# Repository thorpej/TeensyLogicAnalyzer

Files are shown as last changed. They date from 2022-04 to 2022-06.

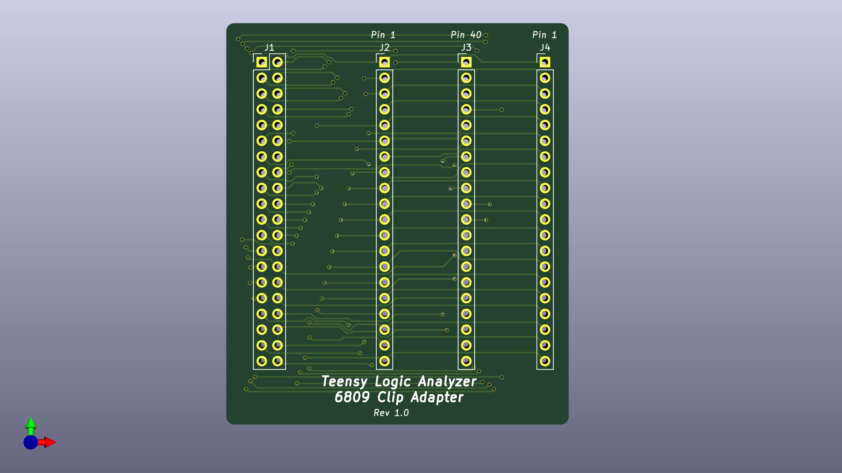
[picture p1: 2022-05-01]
clip-adapter-6809/clip-adapter-6809-pcb.jpg

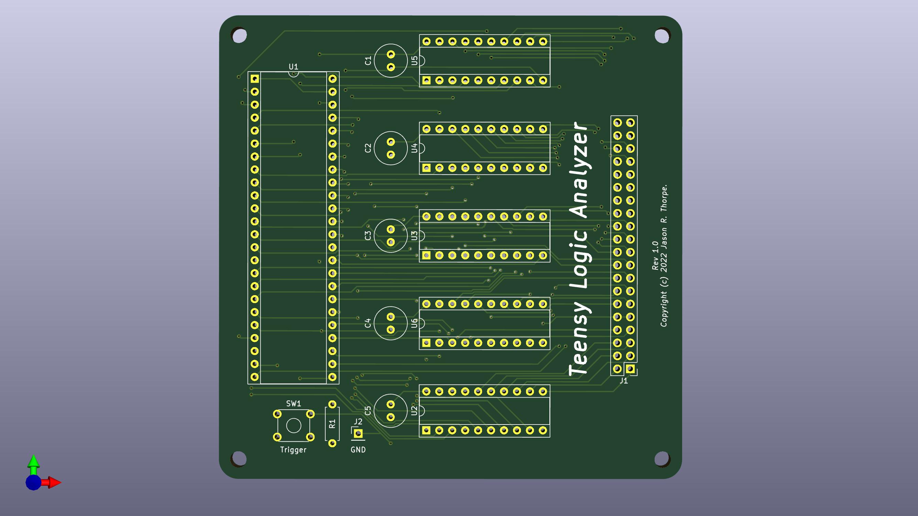
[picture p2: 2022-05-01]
analyzer-board/analyzer-board-pcb.jpg

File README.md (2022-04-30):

# TeensyLogicAnalyzer
Simple logic analyzer for 8-bit CPUs based on Jeff Tranter's 8-bit CPU logic analyzer

This is a work-in-progress.  You can find Jeff's work [here](https://github.com/jefftranter/6502).

This version aims to support a wide variety of 8-bit CPUs (so long as they fit in a 40-pin DIP)
and be easily expandable to new CPU types (e.g. 8080 and 8088) through the use of off-board adapter
modules, as well as to support sampling the full complement of control signals on the supported CPUs.

The main board is very similar to Jeff's original: it contains the Teensy 4.1, input buffers to
level-shift the 5V TTL signals from the target CPU down to the 3.3V levels supported by the Teensy,
a manual trigger button, and a ground reference pin (as a convenience).

The main difference is the use of a single keyed 40-pin IDC header.  This header's pinout does not
correspond directly to any single CPU type, but merely provides the input to the analyzer.
Individual adapter modules mate the analyzer to a specific CPU.  These adapter modules also contain
a 40-pin keyed IDC header, as well as 2 (optionally 3) rows of 1x20 pin headers for connecting a 40-pin
DIP clip to the adapter.  The adapter maps the target CPU's pin configuration to the analyzer's input
pins.  In addition to providing future expandability, it also keeps the manufacturing cost of the boards
low (some PCB fabricators charge as little as $5 + shipping for a run of 10 if the board is smaller
than 100mm x 100mm).  The analyzer board is approximately 91mm x 91mm (roughly 3.5 inches square), and
uses all through-hole components to make it easy to build.

In addition, I plan to make some specific enhancements to the 6809 support, including:
- Support additional signals on the 6809 (e.g. BS, BA, /FIRQ, /HALT).
- Properly notice instruction fetch on 6809E (by watching the LIC signal).
- Improve 6809 dissasembly (decode all of the addressing modes, as well as the 2-byte opcodes).

Beause the 6809E enhancements I want to make require additional signals to be routed, I needed
to make a new board anyway, which is why this project exists.

More to come.  Stay tuned!

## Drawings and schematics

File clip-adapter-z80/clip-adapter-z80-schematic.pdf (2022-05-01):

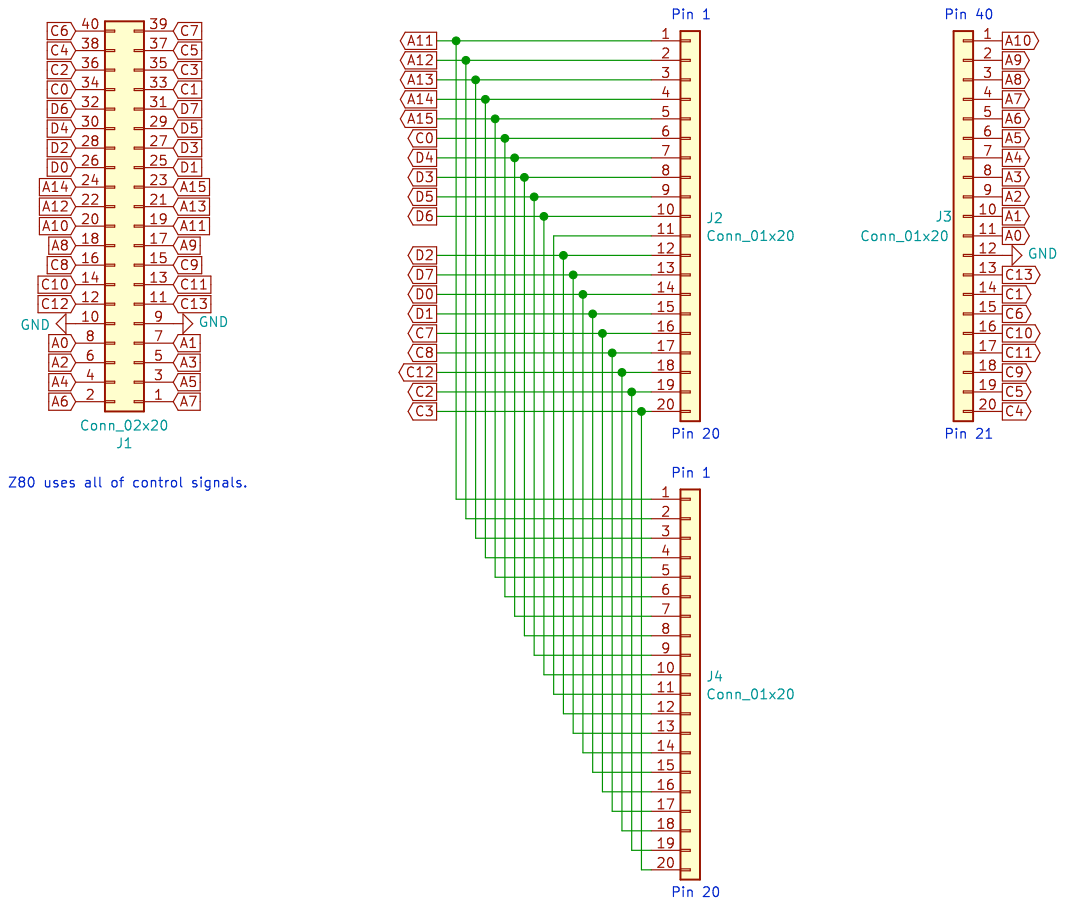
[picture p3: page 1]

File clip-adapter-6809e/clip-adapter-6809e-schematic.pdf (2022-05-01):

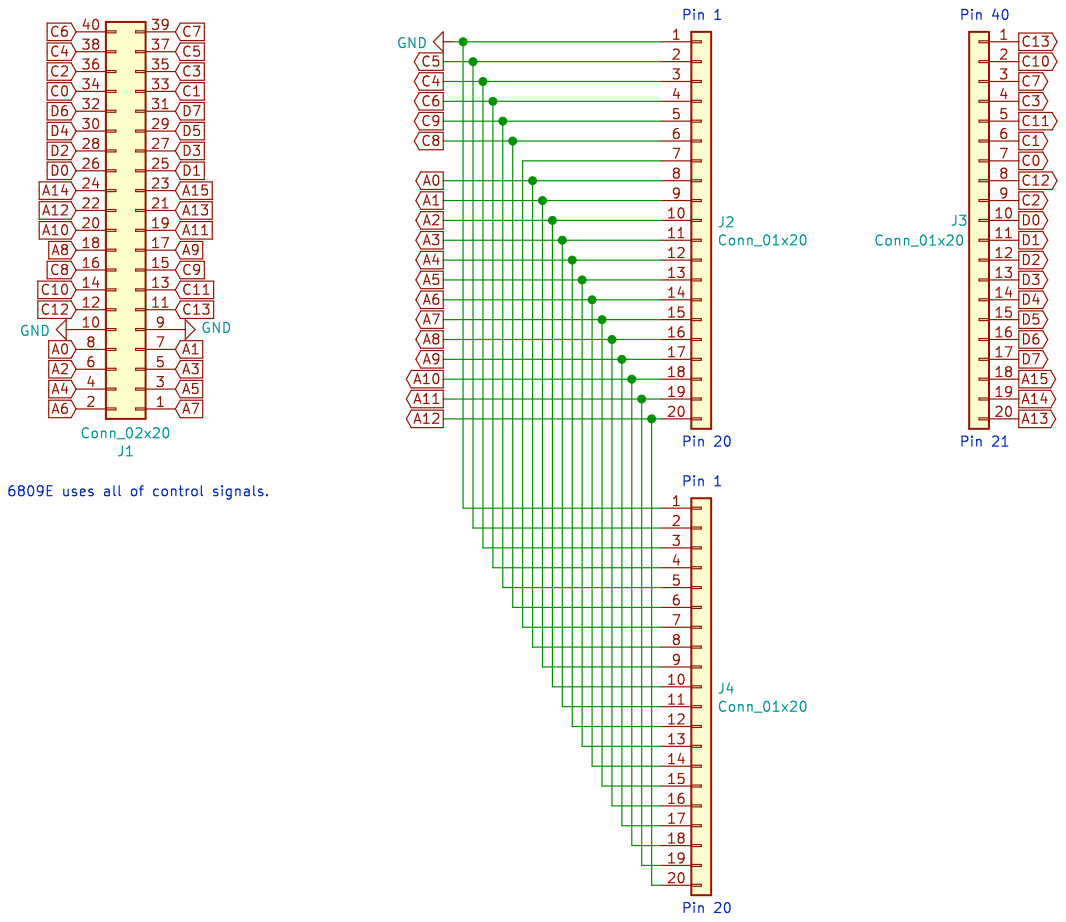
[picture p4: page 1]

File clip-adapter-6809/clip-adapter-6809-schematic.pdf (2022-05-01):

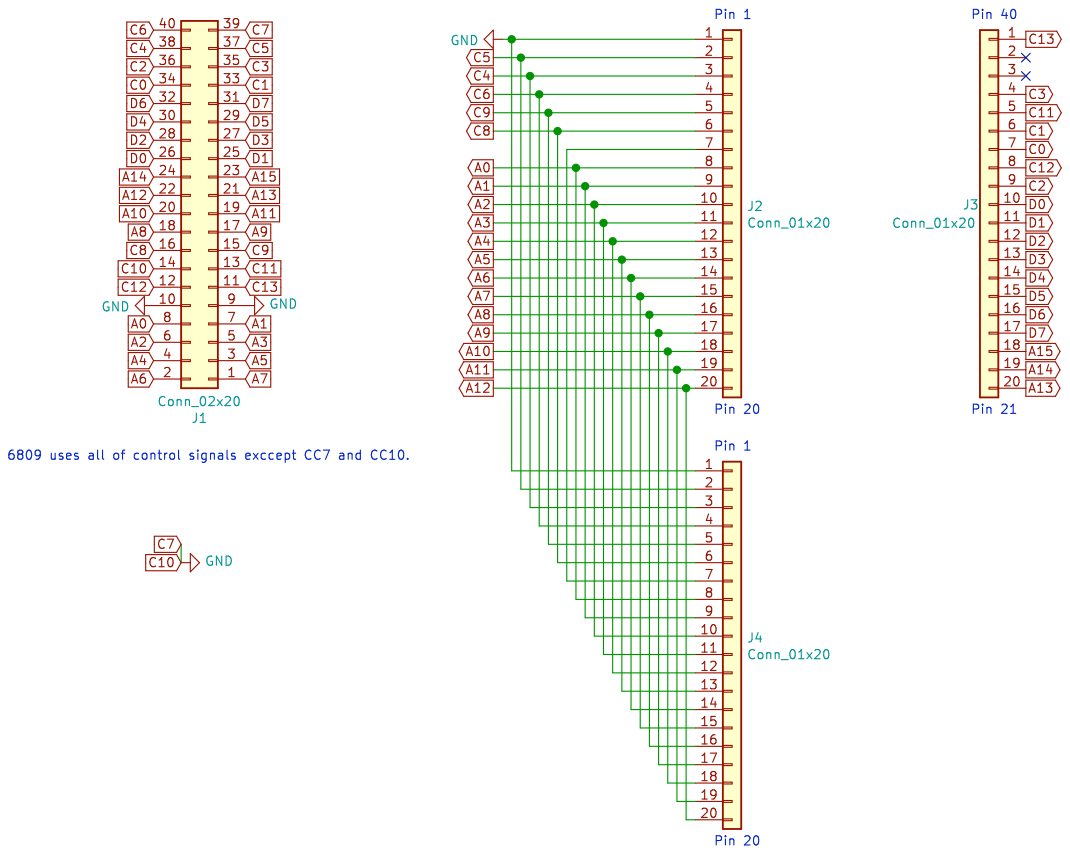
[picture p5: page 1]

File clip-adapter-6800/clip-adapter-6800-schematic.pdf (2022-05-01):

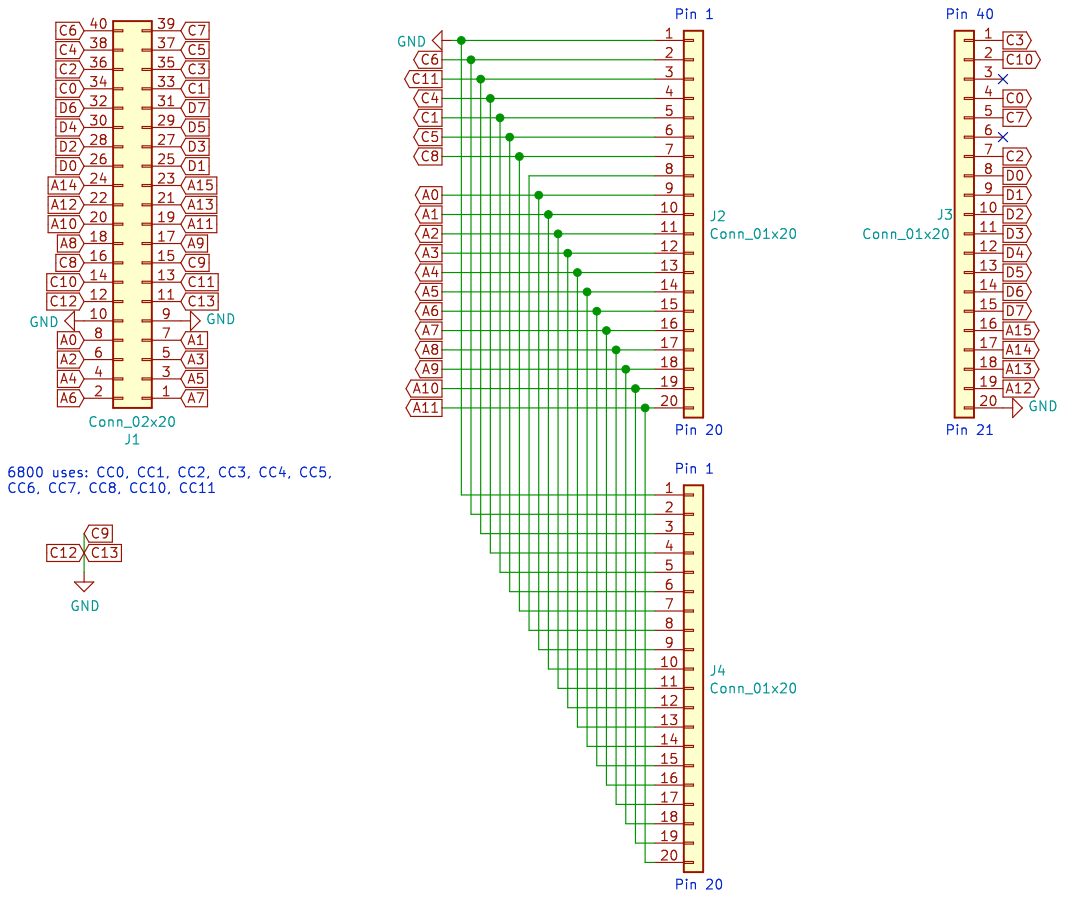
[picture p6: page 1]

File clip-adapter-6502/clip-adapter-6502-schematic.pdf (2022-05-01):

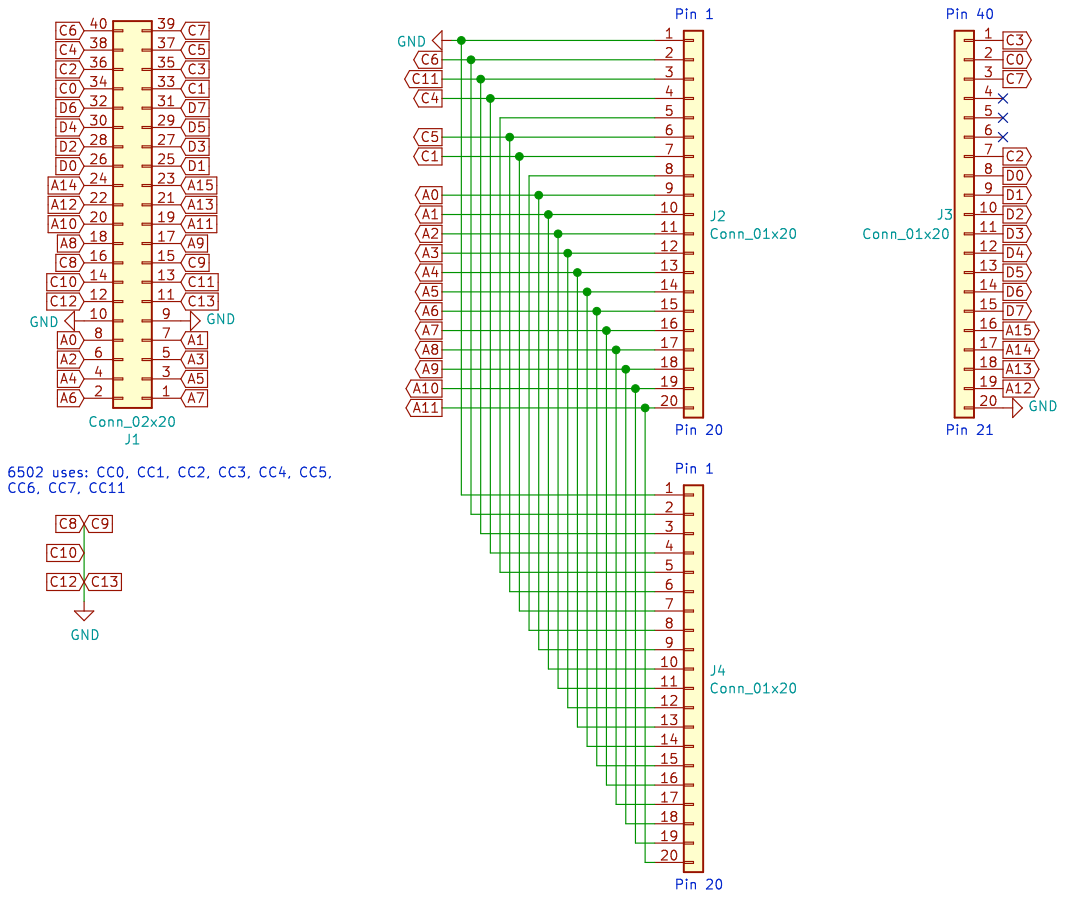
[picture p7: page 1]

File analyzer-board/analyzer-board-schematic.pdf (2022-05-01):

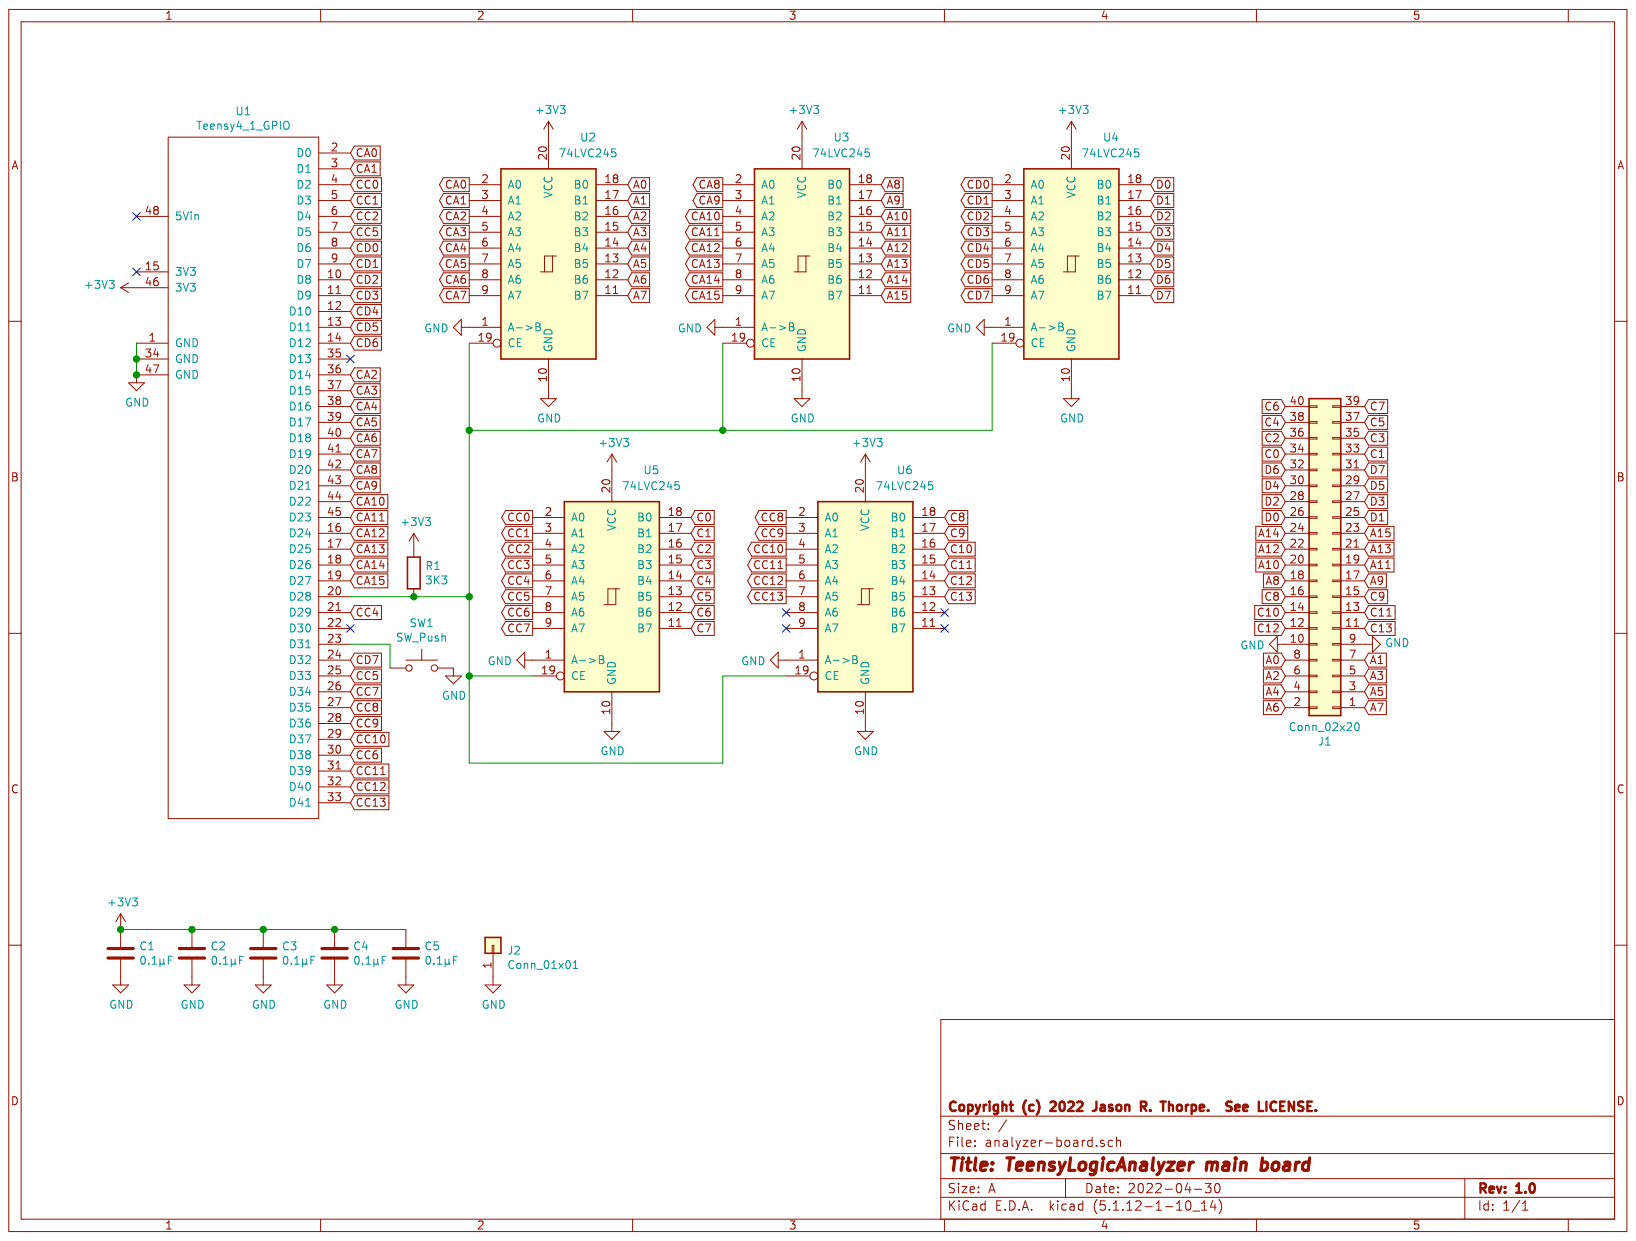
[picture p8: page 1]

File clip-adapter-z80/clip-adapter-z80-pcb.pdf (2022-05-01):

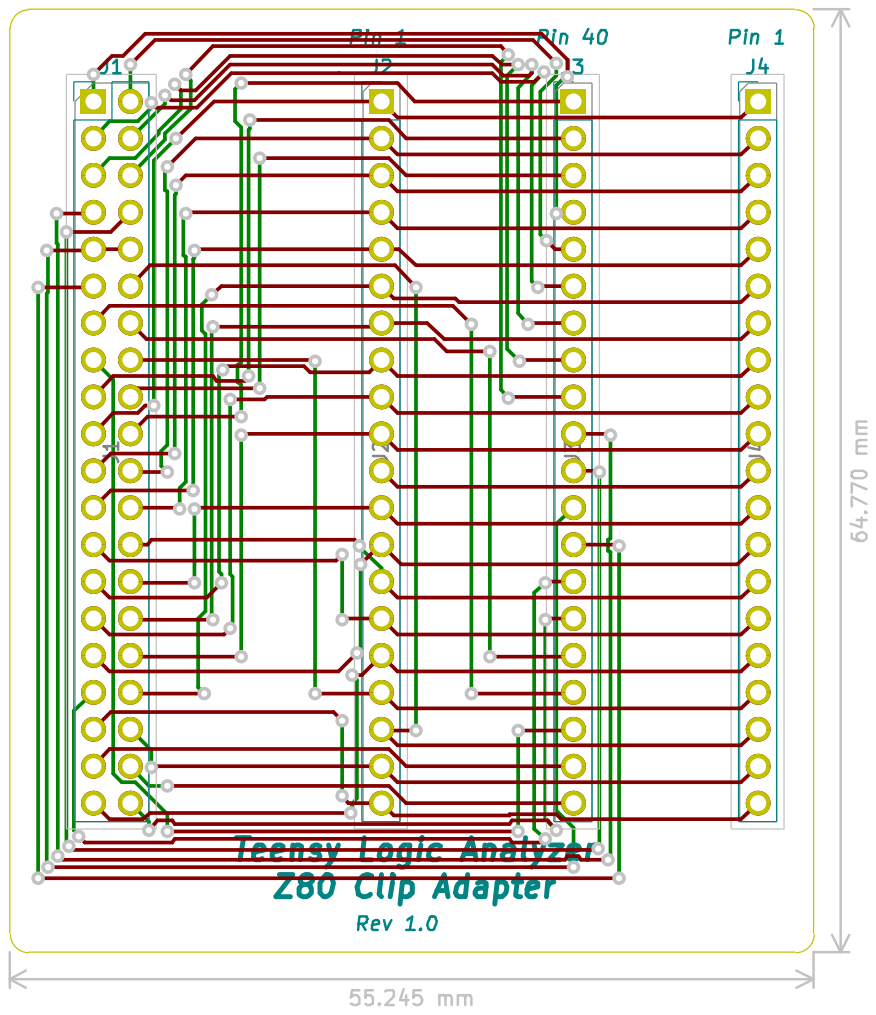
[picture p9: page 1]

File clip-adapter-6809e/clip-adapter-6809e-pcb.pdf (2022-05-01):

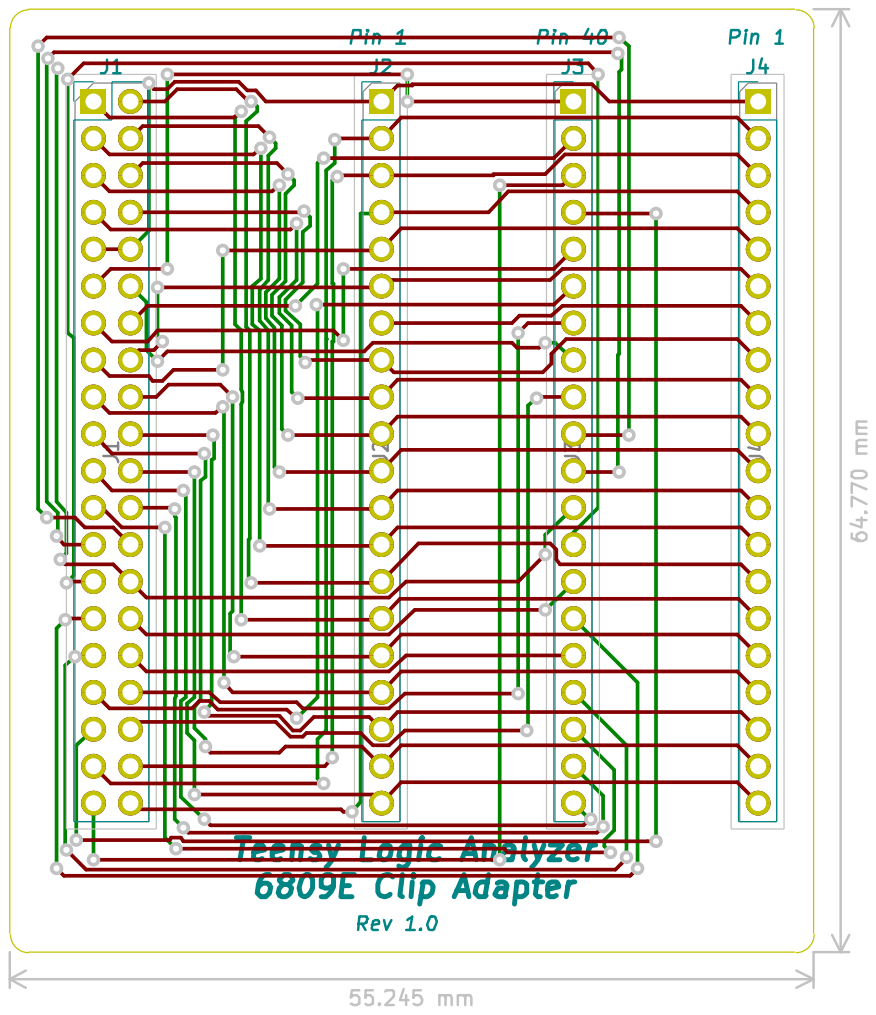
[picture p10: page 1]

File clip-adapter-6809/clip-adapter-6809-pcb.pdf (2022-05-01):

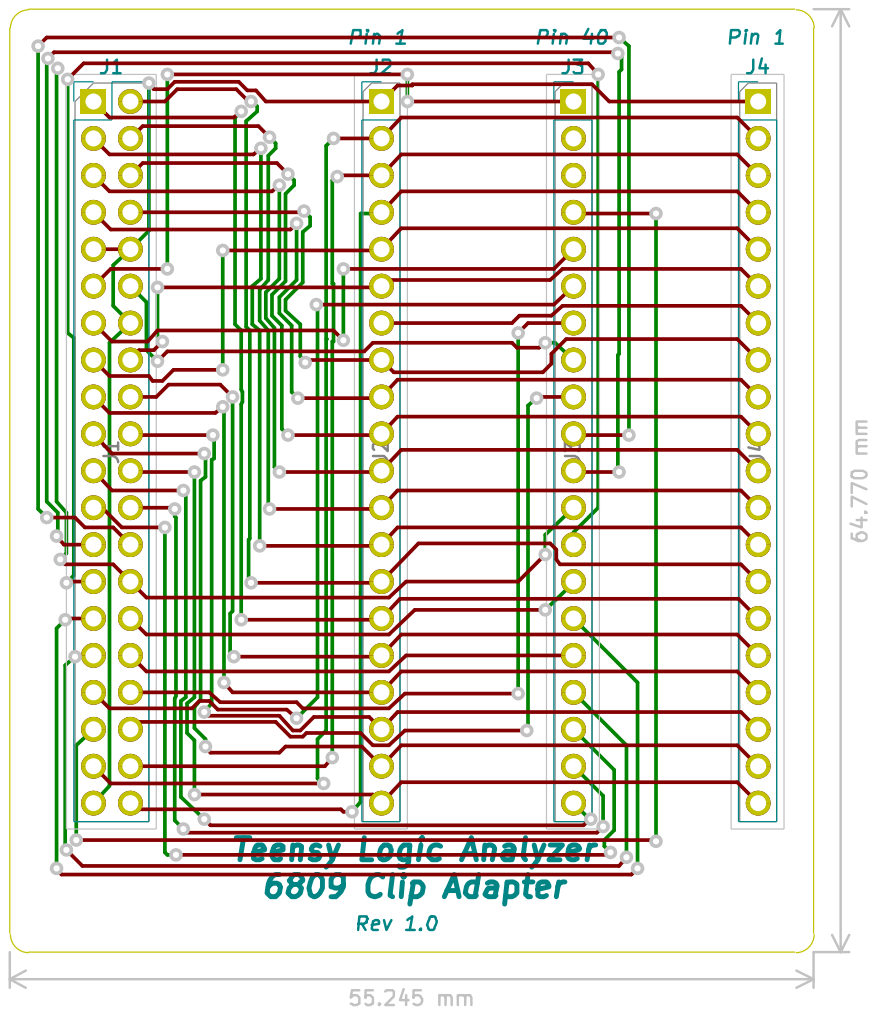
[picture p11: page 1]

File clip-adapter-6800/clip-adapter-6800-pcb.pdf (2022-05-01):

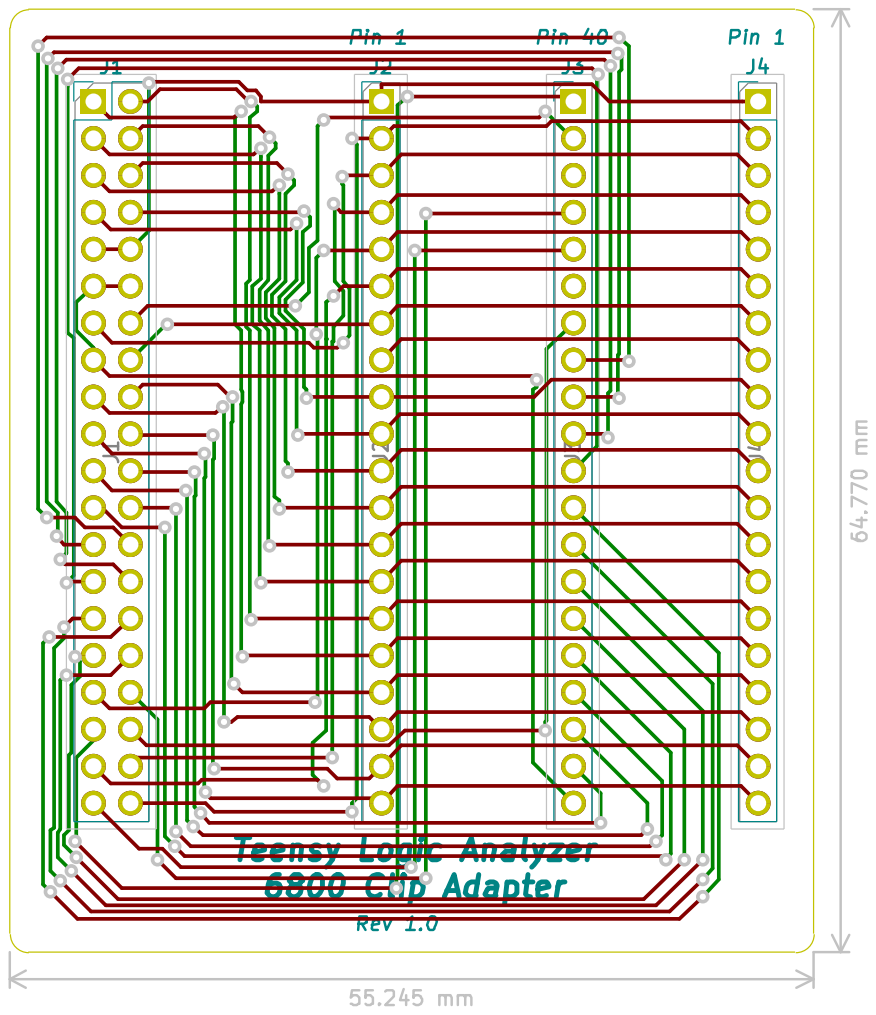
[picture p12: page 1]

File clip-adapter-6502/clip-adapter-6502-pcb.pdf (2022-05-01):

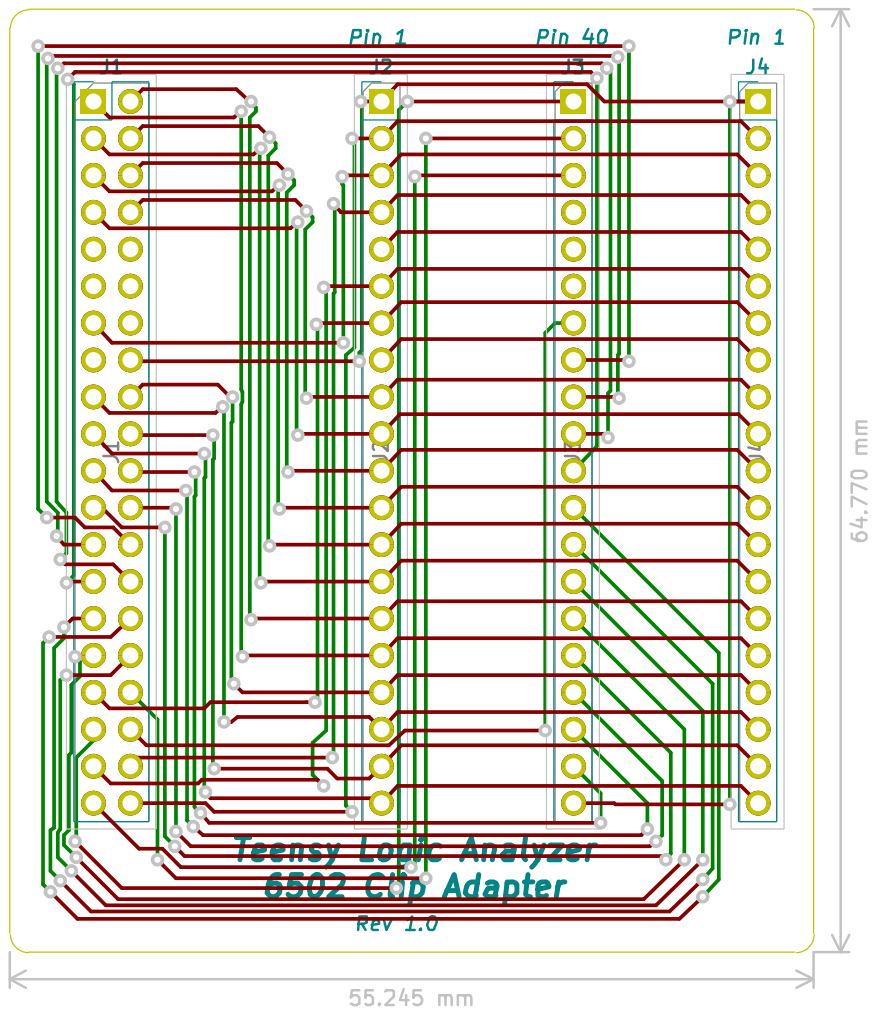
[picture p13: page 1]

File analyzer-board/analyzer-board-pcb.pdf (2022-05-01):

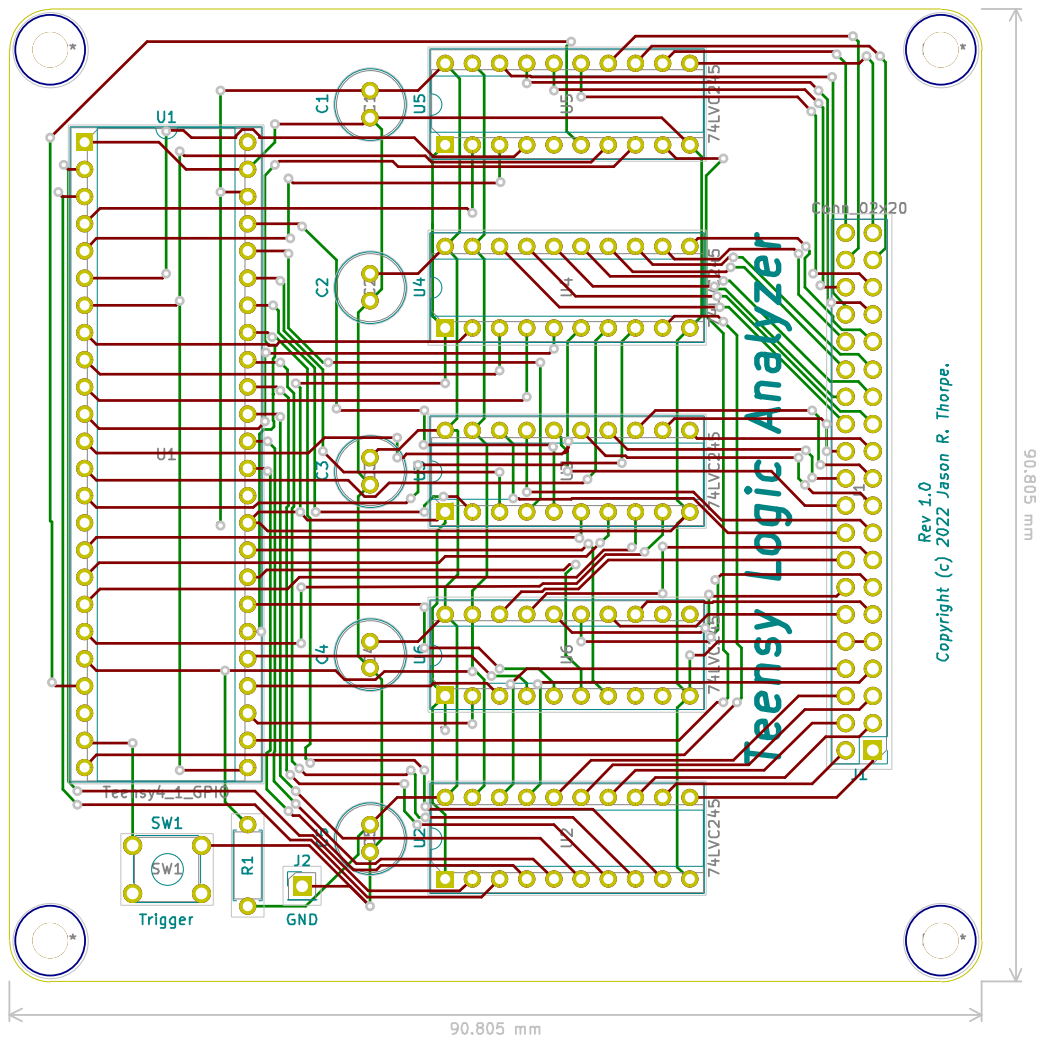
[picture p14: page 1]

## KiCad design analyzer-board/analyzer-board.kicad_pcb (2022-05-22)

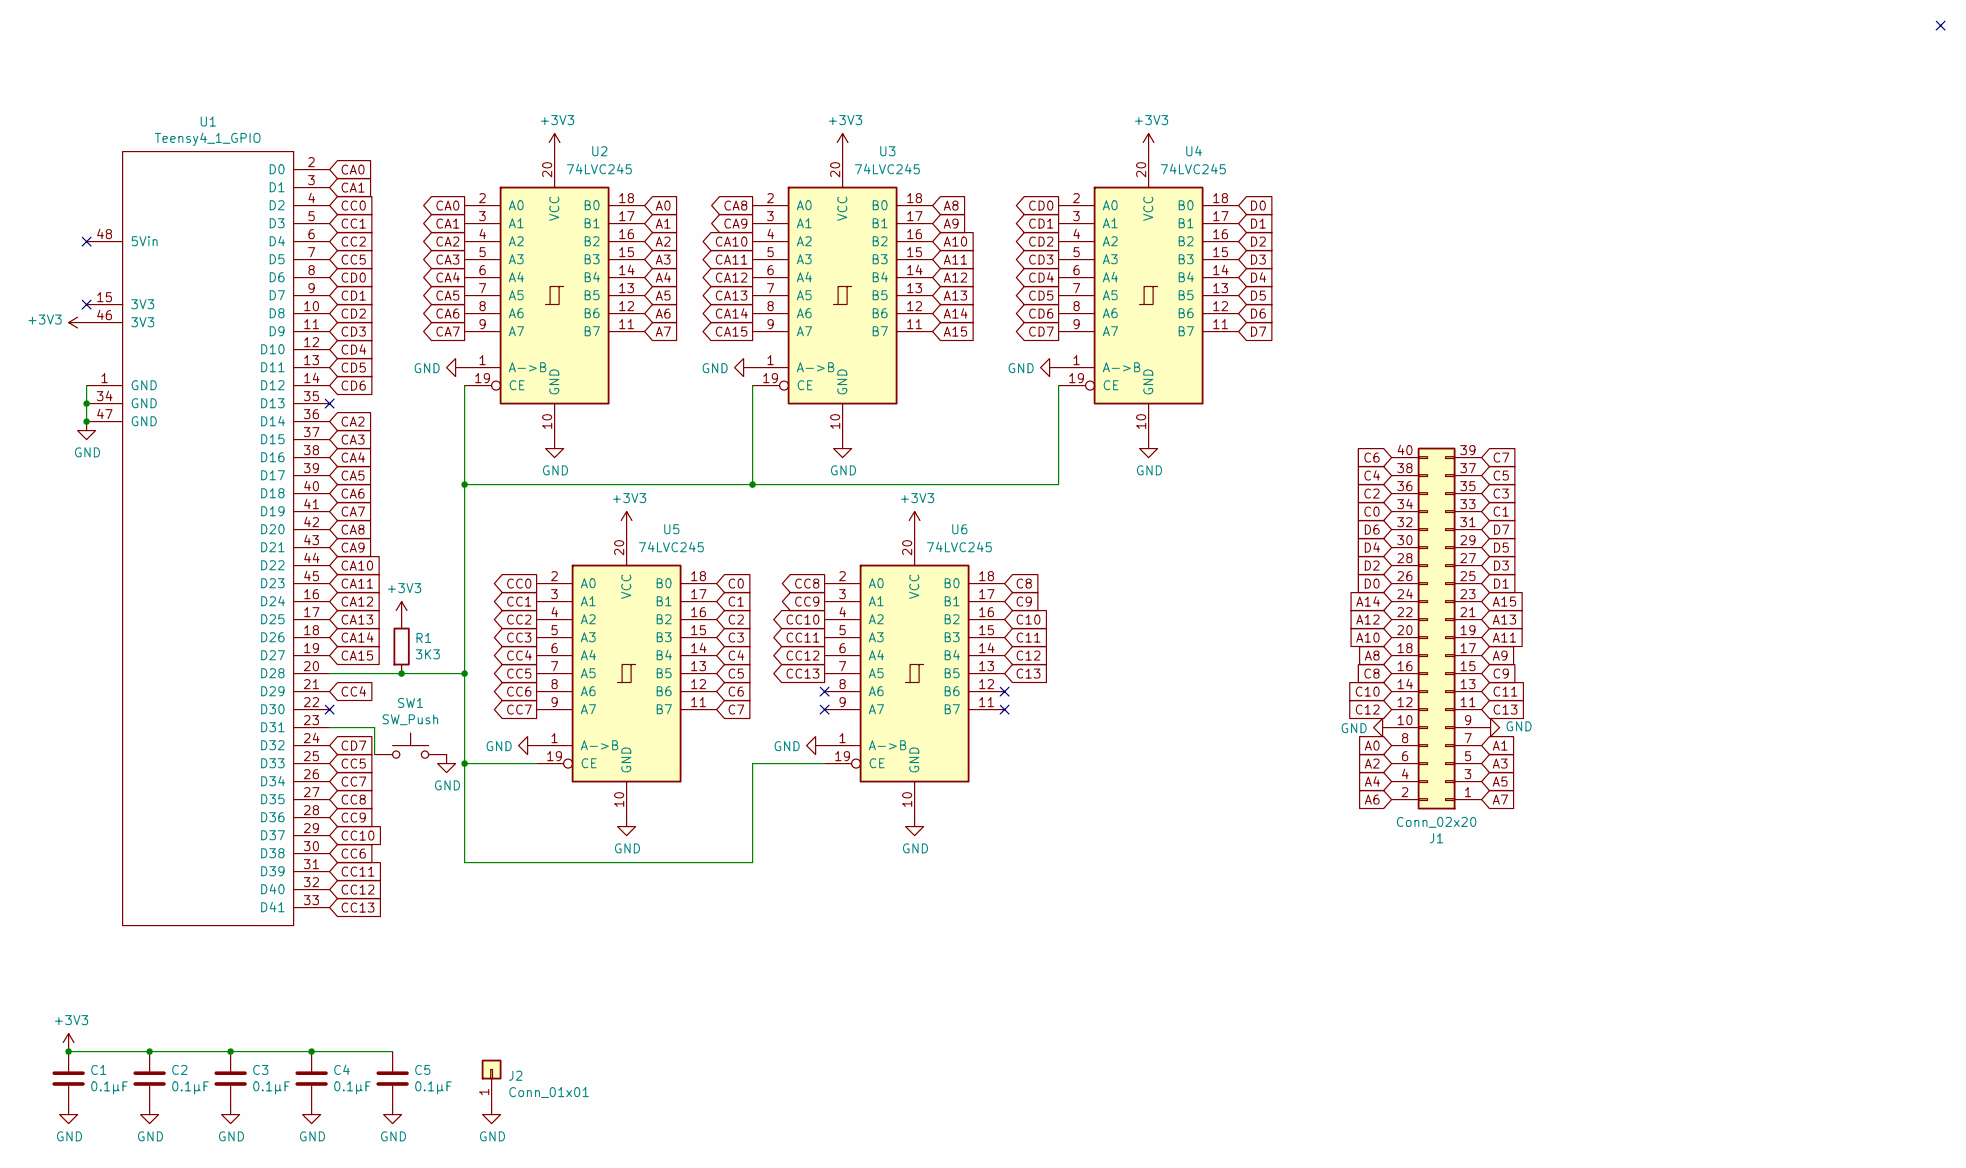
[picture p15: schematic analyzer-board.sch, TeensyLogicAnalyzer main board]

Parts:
C1, C2, C3, C4, C5: 0.1µF; C_Radial_D6.3mm_H5.0mm_P2.50mm; Mouser 80-C320C104K2R5TA
J1: Conn_02x20; PinHeader_2x20_P2.54mm_Vertical
J2: Conn_01x01; PinHeader_1x01_P2.54mm_Vertical
R1: 3K3; R_Axial_DIN0207_L6.3mm_D2.5mm_P7.62mm_Horizontal
SW1: SW_Push; SW_PUSH_6mm
U1: Teensy4_1_GPIO; DIP-48_W15.24mm_Socket
U2, U3, U4, U5, U6: 74LVC245; DIP-20_W7.62mm_Socket

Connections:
+3V3: C1.1, C2.1, C3.1, C4.1, C5.1, R1.1, U1.46 (3V3), U2.20 (VCC), U3.20 (VCC), U4.20 (VCC), U5.20 (VCC), U6.20 (VCC)
A0: J1.8, U2.18 (B0)
A1: J1.7, U2.17 (B1)
A2: J1.6, U2.16 (B2)
A3: J1.5, U2.15 (B3)
A4: J1.4, U2.14 (B4)
A5: J1.3, U2.13 (B5)
A6: J1.2, U2.12 (B6)
A7: J1.1, U2.11 (B7)
A8: J1.18, U3.18 (B0)
A9: J1.17, U3.17 (B1)
A10: J1.20, U3.16 (B2)
A11: J1.19, U3.15 (B3)
A12: J1.22, U3.14 (B4)
A13: J1.21, U3.13 (B5)
A14: J1.24, U3.12 (B6)
A15: J1.23, U3.11 (B7)
C0: J1.34, U5.18 (B0)
C1: J1.33, U5.17 (B1)
C2: J1.36, U5.16 (B2)
C3: J1.35, U5.15 (B3)
C4: J1.38, U5.14 (B4)
C5: J1.37, U5.13 (B5)
C6: J1.40, U5.12 (B6)
C7: J1.39, U5.11 (B7)
C8: J1.16, U6.18 (B0)
C9: J1.15, U6.17 (B1)
C10: J1.14, U6.16 (B2)
C11: J1.13, U6.15 (B3)
C12: J1.12, U6.14 (B4)
C13: J1.11, U6.13 (B5)
CA0: U1.2 (D0), U2.2 (A0)
CA1: U1.3 (D1), U2.3 (A1)
CA2: U1.36 (D14), U2.4 (A2)
CA3: U1.37 (D15), U2.5 (A3)
CA4: U1.38 (D16), U2.6 (A4)
CA5: U1.39 (D17), U2.7 (A5)
CA6: U1.40 (D18), U2.8 (A6)
CA7: U1.41 (D19), U2.9 (A7)
CA8: U1.42 (D20), U3.2 (A0)
CA9: U1.43 (D21), U3.3 (A1)
CA10: U1.44 (D22), U3.4 (A2)
CA11: U1.45 (D23), U3.5 (A3)
CA12: U1.16 (D24), U3.6 (A4)
CA13: U1.17 (D25), U3.7 (A5)
CA14: U1.18 (D26), U3.8 (A6)
CA15: U1.19 (D27), U3.9 (A7)
CC0: U1.4 (D2), U5.2 (A0)
CC1: U1.5 (D3), U5.3 (A1)
CC2: U1.6 (D4), U5.4 (A2)
CC3: U5.5 (A3)
CC4: U1.21 (D29), U5.6 (A4)
CC5: U1.7 (D5), U1.25 (D33), U5.7 (A5)
CC6: U1.30 (D38), U5.8 (A6)
CC7: U1.26 (D34), U5.9 (A7)
CC8: U1.27 (D35), U6.2 (A0)
CC9: U1.28 (D36), U6.3 (A1)
CC10: U1.29 (D37), U6.4 (A2)
CC11: U1.31 (D39), U6.5 (A3)
CC12: U1.32 (D40), U6.6 (A4)
CC13: U1.33 (D41), U6.7 (A5)
CD0: U1.8 (D6), U4.2 (A0)
CD1: U1.9 (D7), U4.3 (A1)
CD2: U1.10 (D8), U4.4 (A2)
CD3: U1.11 (D9), U4.5 (A3)
CD4: U1.12 (D10), U4.6 (A4)
CD5: U1.13 (D11), U4.7 (A5)
CD6: U1.14 (D12), U4.8 (A6)
CD7: U1.24 (D32), U4.9 (A7)
D0: J1.26, U4.18 (B0)
D1: J1.25, U4.17 (B1)
D2: J1.28, U4.16 (B2)
D3: J1.27, U4.15 (B3)
D4: J1.30, U4.14 (B4)
D5: J1.29, U4.13 (B5)
D6: J1.32, U4.12 (B6)
D7: J1.31, U4.11 (B7)
GND: C1.2, C2.2, C3.2, C4.2, C5.2, J1.9, J1.10, J2.1, SW1.2, U1.1 (GND), U1.34 (GND), U1.47 (GND), U2.1 (A->B), U2.10 (GND), U3.1 (A->B), U3.10 (GND), U4.1 (A->B), U4.10 (GND), U5.1 (A->B), U5.10 (GND), U6.1 (A->B), U6.10 (GND)
unnamed: R1.2, U1.20 (D28), U2.19 (CE), U3.19 (CE), U4.19 (CE), U5.19 (CE), U6.19 (CE)
unnamed: SW1.1, U1.23 (D31)

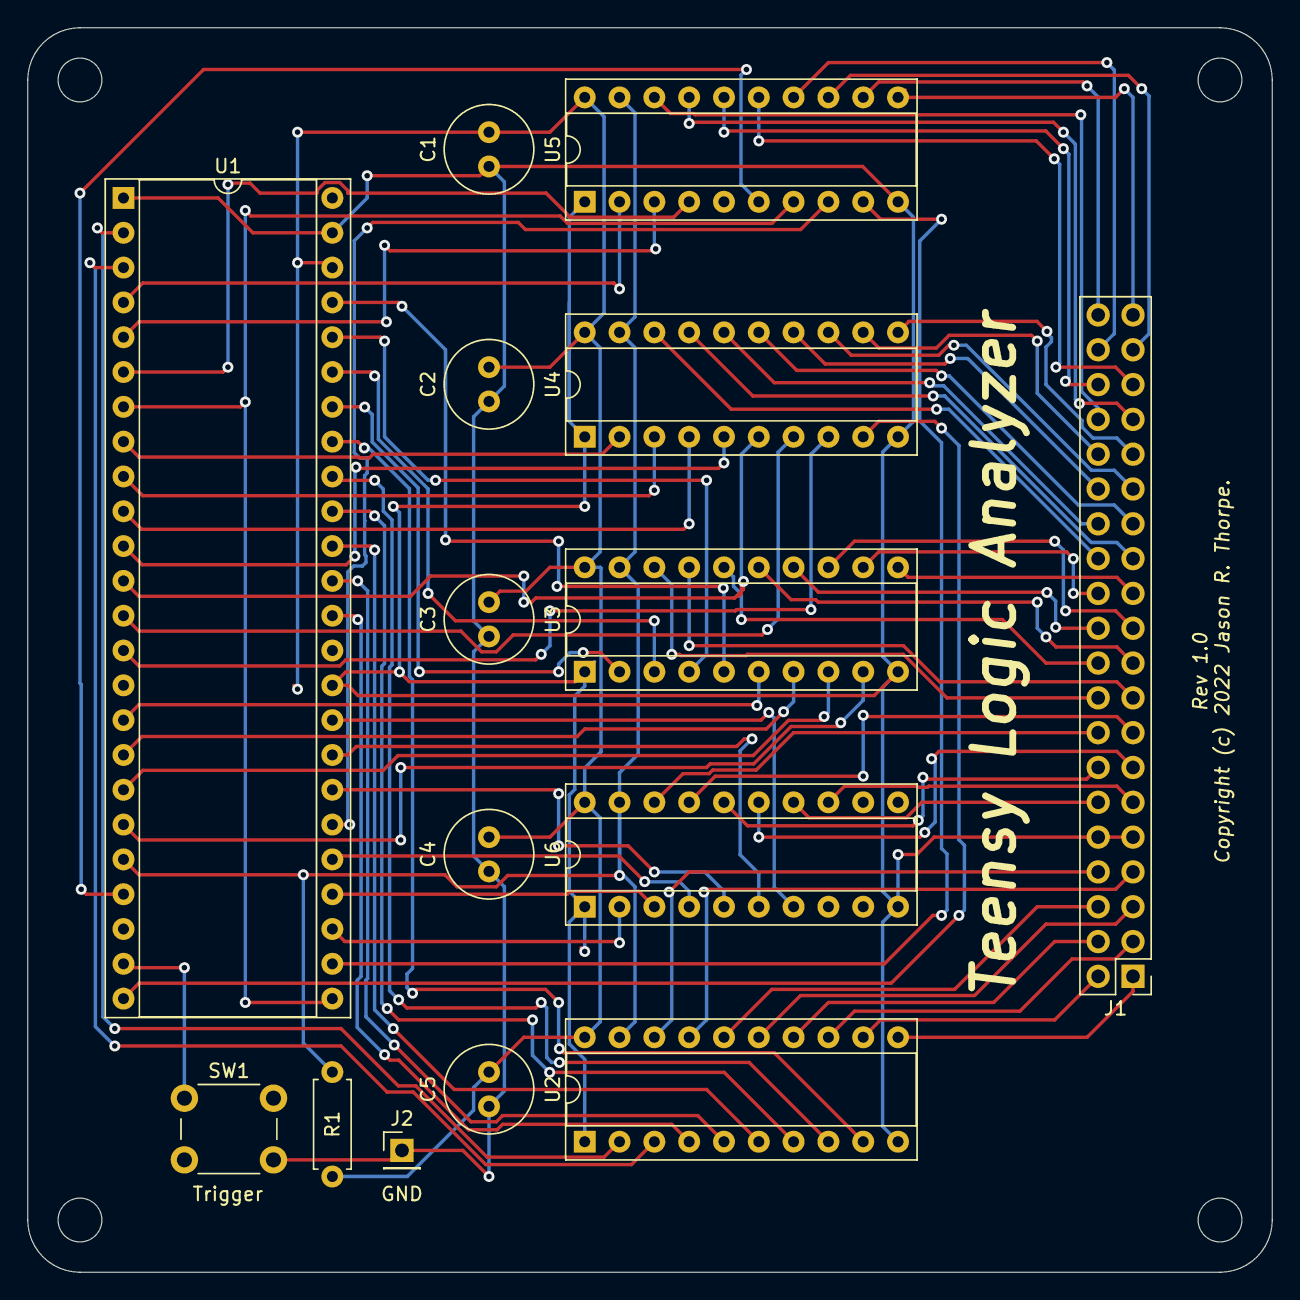
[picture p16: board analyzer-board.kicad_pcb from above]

Board: 2 copper layers, 90.8 x 90.8 mm, 15 parts (0 on the bottom side), 79 nets.

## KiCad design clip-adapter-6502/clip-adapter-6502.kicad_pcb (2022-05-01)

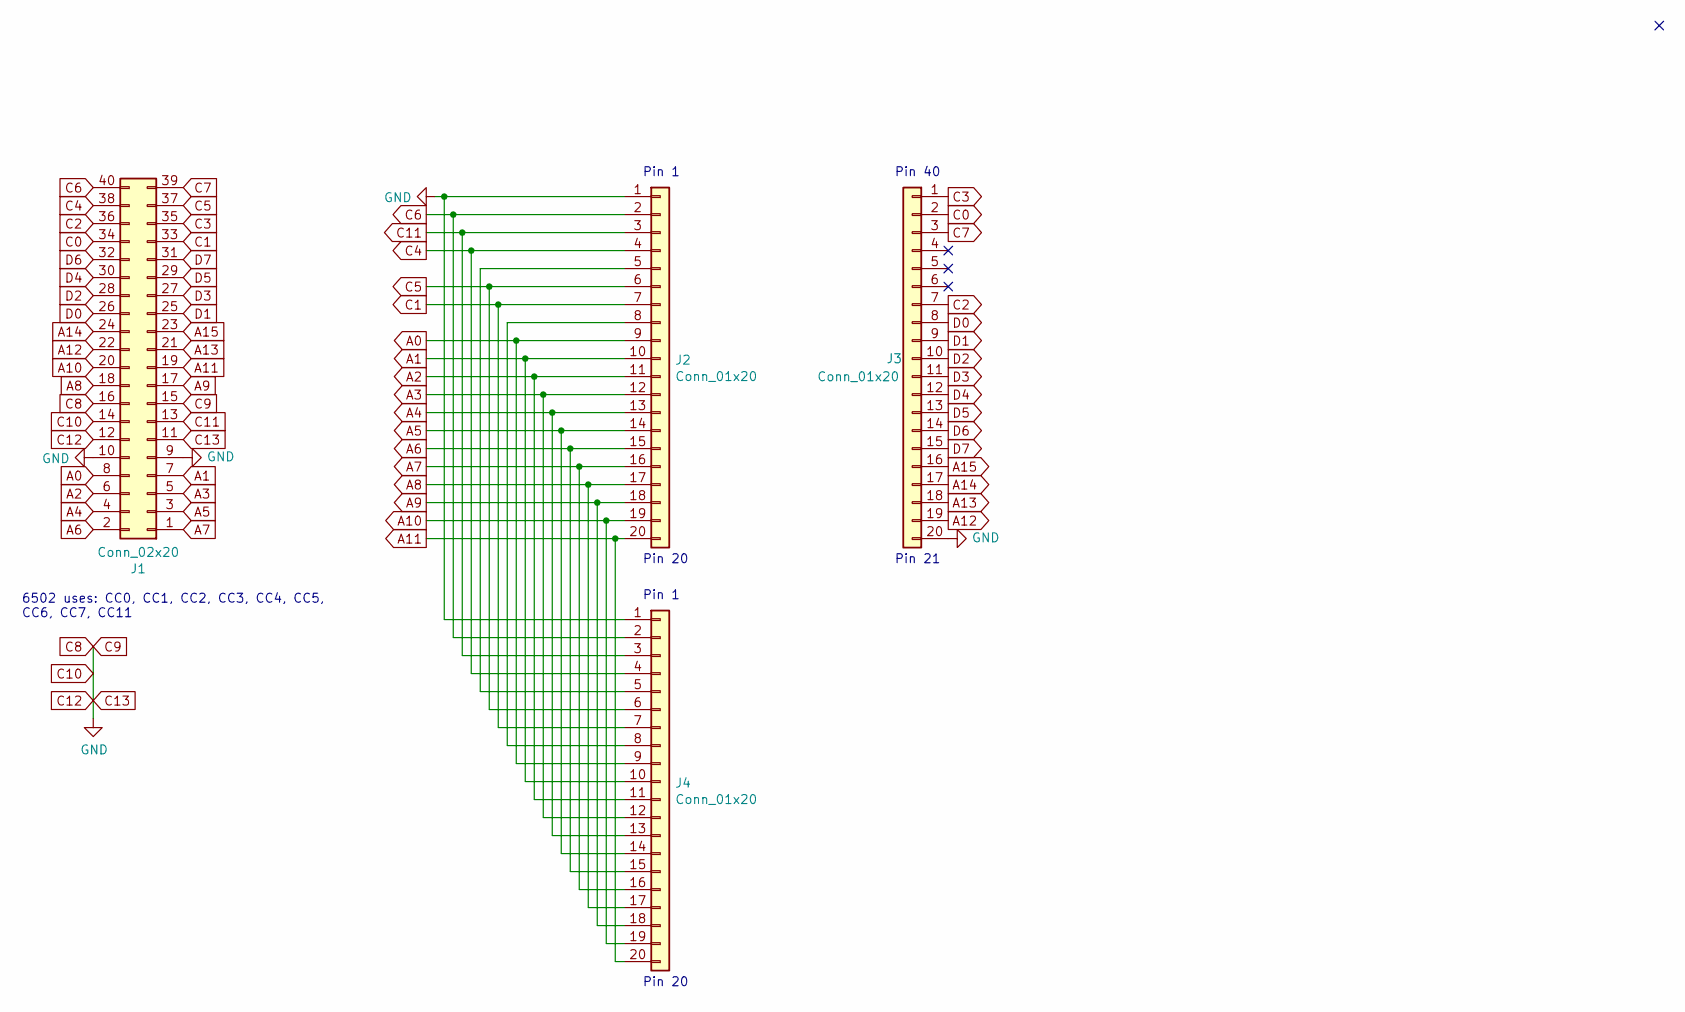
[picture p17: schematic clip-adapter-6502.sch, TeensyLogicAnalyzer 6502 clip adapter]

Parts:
J1: Conn_02x20; PinHeader_2x20_P2.54mm_Vertical
J2, J3, J4: Conn_01x20; PinHeader_1x20_P2.54mm_Vertical

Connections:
A0: J1.8, J2.9, J4.9
A1: J1.7, J2.10, J4.10
A2: J1.6, J2.11, J4.11
A3: J1.5, J2.12, J4.12
A4: J1.4, J2.13, J4.13
A5: J1.3, J2.14, J4.14
A6: J1.2, J2.15, J4.15
A7: J1.1, J2.16, J4.16
A8: J1.18, J2.17, J4.17
A9: J1.17, J2.18, J4.18
A10: J1.20, J2.19, J4.19
A11: J1.19, J2.20, J4.20
A12: J1.22, J3.19
A13: J1.21, J3.18
A14: J1.24, J3.17
A15: J1.23, J3.16
C0: J1.34, J3.2
C1: J1.33, J2.7, J4.7
C2: J1.36, J3.7
C3: J1.35, J3.1
C4: J1.38, J2.4, J4.4
C5: J1.37, J2.6, J4.6
C6: J1.40, J2.2, J4.2
C7: J1.39, J3.3
C10: J1.9, J1.10, J1.11, J1.12, J1.14, J1.15, J1.16, J2.1, J3.20, J4.1
C11: J1.13, J2.3, J4.3
D0: J1.26, J3.8
D1: J1.25, J3.9
D2: J1.28, J3.10
D3: J1.27, J3.11
D4: J1.30, J3.12
D5: J1.29, J3.13
D6: J1.32, J3.14
D7: J1.31, J3.15
unnamed: J2.5, J4.5
unnamed: J2.8, J4.8

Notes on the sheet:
Pin 1
Pin 20
Pin 21
Pin 40
6502 uses: CC0, CC1, CC2, CC3, CC4, CC5, CC6, CC7, CC11

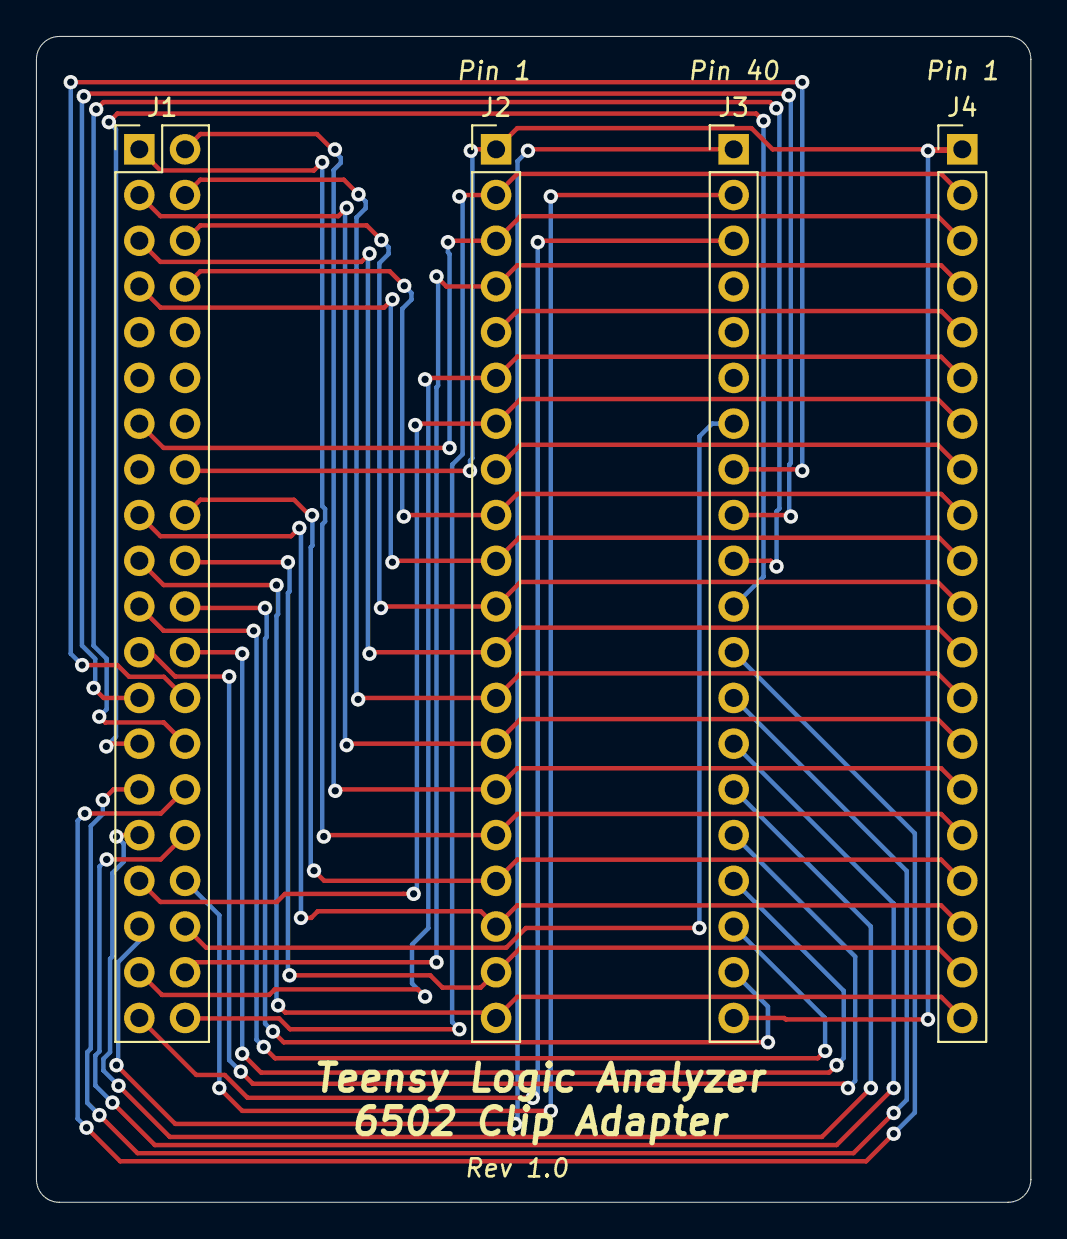
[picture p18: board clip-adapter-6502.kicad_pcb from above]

Board: 2 copper layers, 55.2 x 64.8 mm, 4 parts (0 on the bottom side), 36 nets.

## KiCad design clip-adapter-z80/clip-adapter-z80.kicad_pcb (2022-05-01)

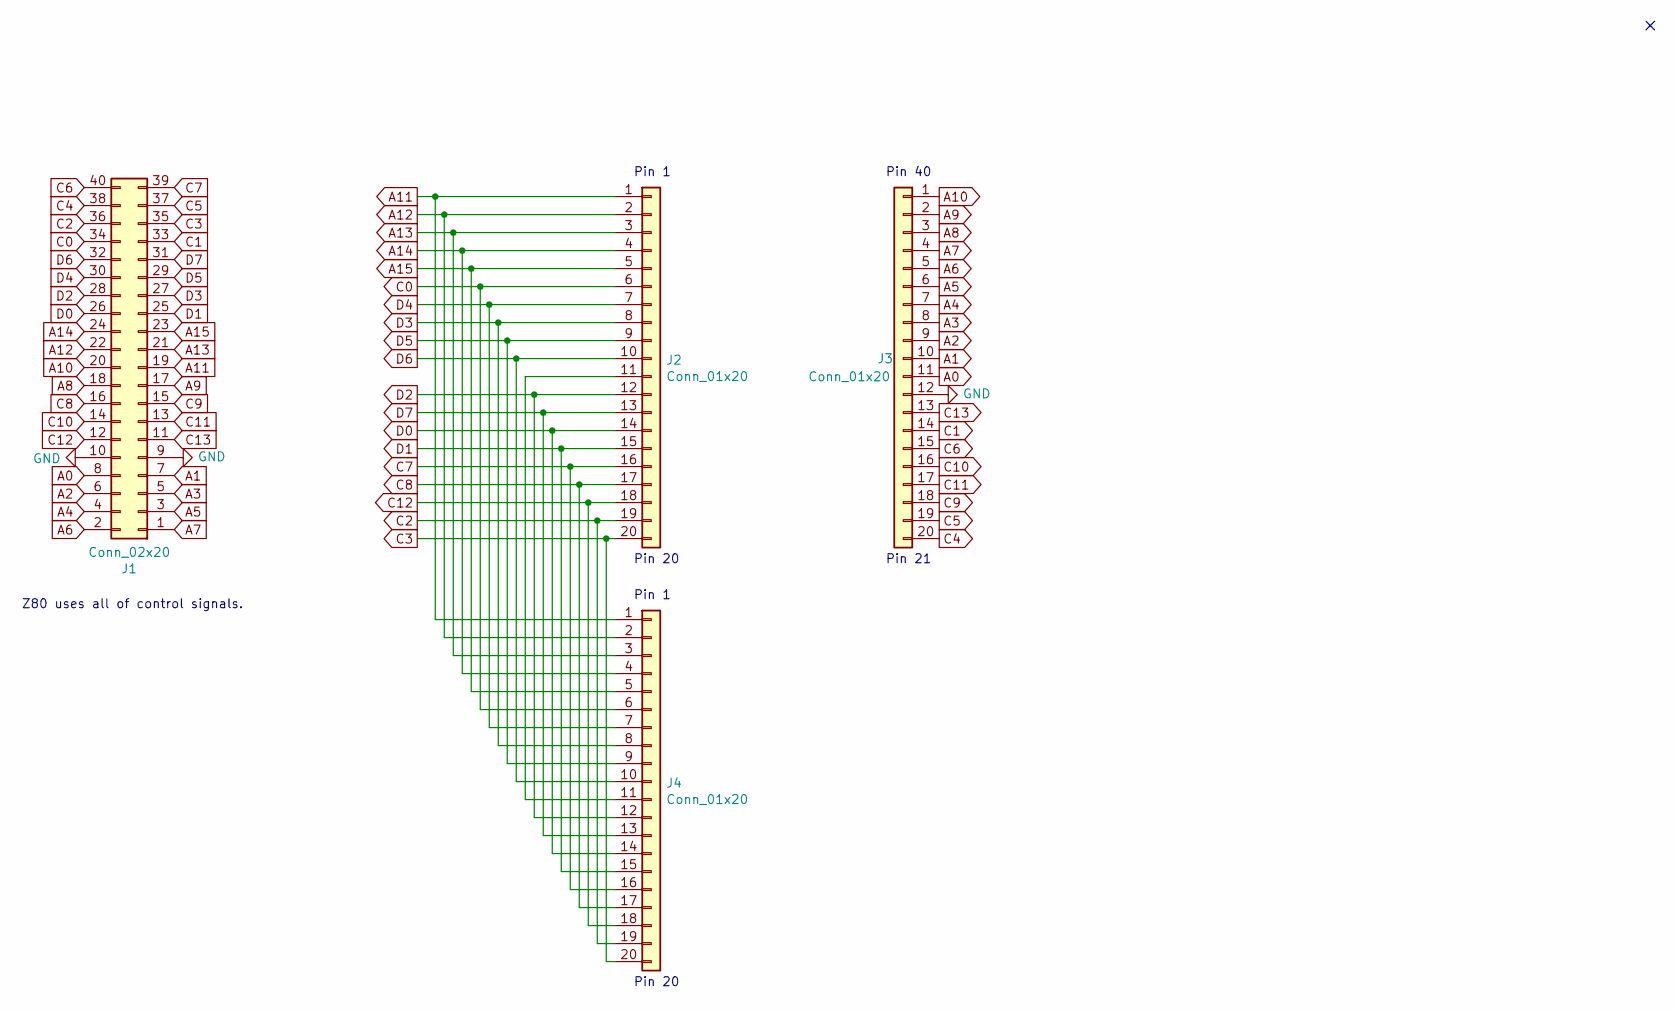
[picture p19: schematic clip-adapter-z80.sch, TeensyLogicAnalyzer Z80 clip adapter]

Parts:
J1: Conn_02x20; PinHeader_2x20_P2.54mm_Vertical
J2, J3, J4: Conn_01x20; PinHeader_1x20_P2.54mm_Vertical

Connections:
A0: J1.8, J3.11
A1: J1.7, J3.10
A2: J1.6, J3.9
A3: J1.5, J3.8
A4: J1.4, J3.7
A5: J1.3, J3.6
A6: J1.2, J3.5
A7: J1.1, J3.4
A8: J1.18, J3.3
A9: J1.17, J3.2
A10: J1.20, J3.1
A11: J1.19, J2.1, J4.1
A12: J1.22, J2.2, J4.2
A13: J1.21, J2.3, J4.3
A14: J1.24, J2.4, J4.4
A15: J1.23, J2.5, J4.5
C0: J1.34, J2.6, J4.6
C1: J1.33, J3.14
C2: J1.36, J2.19, J4.19
C3: J1.35, J2.20, J4.20
C4: J1.38, J3.20
C5: J1.37, J3.19
C6: J1.40, J3.15
C7: J1.39, J2.16, J4.16
C8: J1.16, J2.17, J4.17
C9: J1.15, J3.18
C10: J1.14, J3.16
C11: J1.13, J3.17
C12: J1.12, J2.18, J4.18
C13: J1.11, J3.13
D0: J1.26, J2.14, J4.14
D1: J1.25, J2.15, J4.15
D2: J1.28, J2.12, J4.12
D3: J1.27, J2.8, J4.8
D4: J1.30, J2.7, J4.7
D5: J1.29, J2.9, J4.9
D6: J1.32, J2.10, J4.10
D7: J1.31, J2.13, J4.13
GND: J1.9, J1.10, J3.12
unnamed: J2.11, J4.11

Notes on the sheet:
Pin 1
Pin 20
Pin 21
Pin 40
Z80 uses all of control signals.

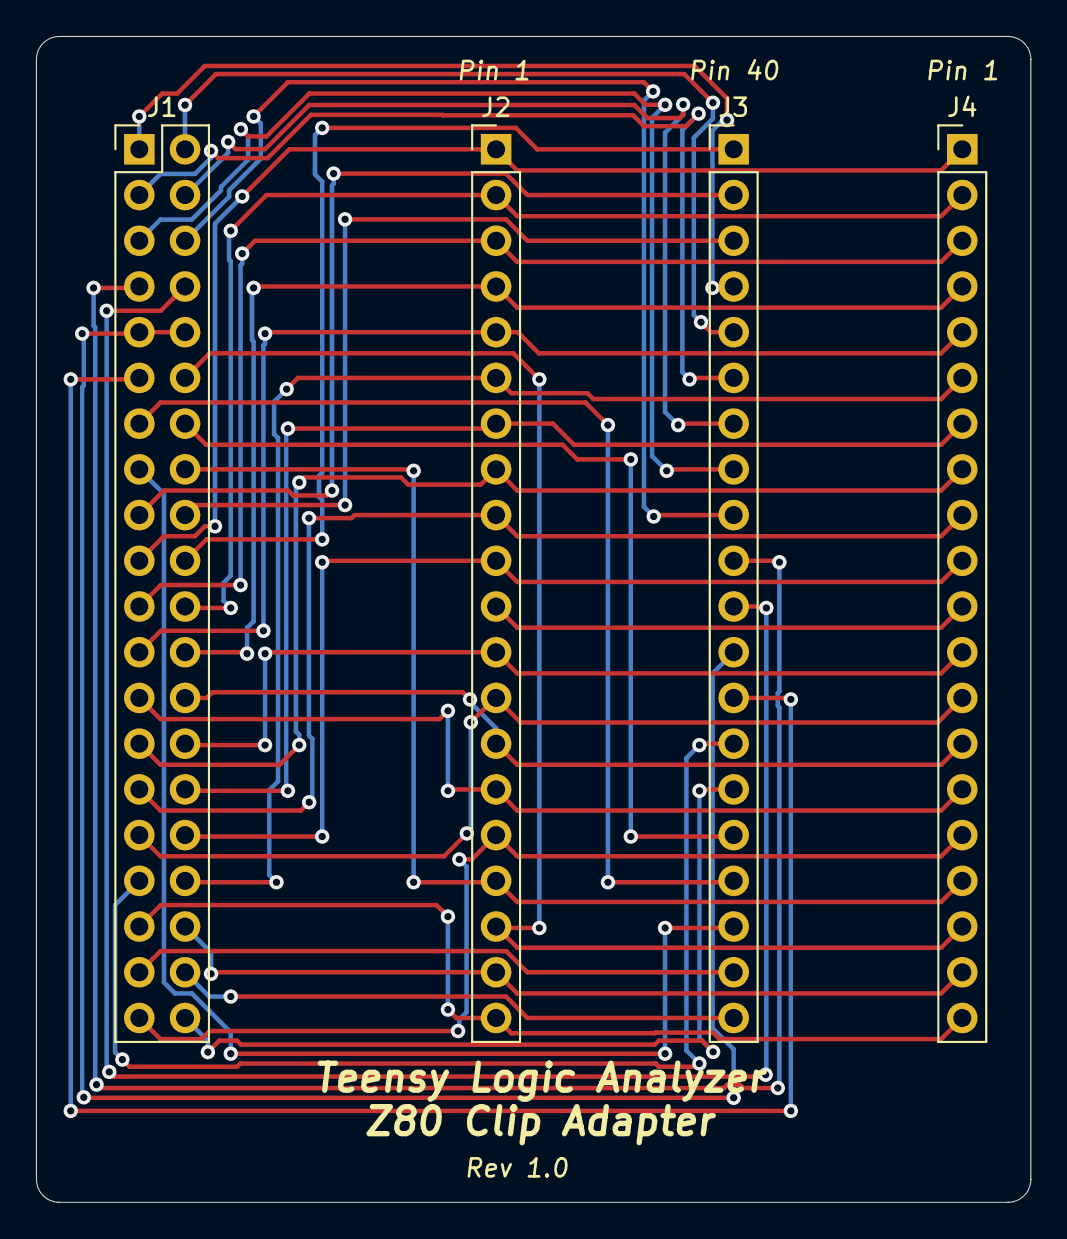
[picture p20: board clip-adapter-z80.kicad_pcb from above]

Board: 2 copper layers, 55.2 x 64.8 mm, 4 parts (0 on the bottom side), 40 nets.

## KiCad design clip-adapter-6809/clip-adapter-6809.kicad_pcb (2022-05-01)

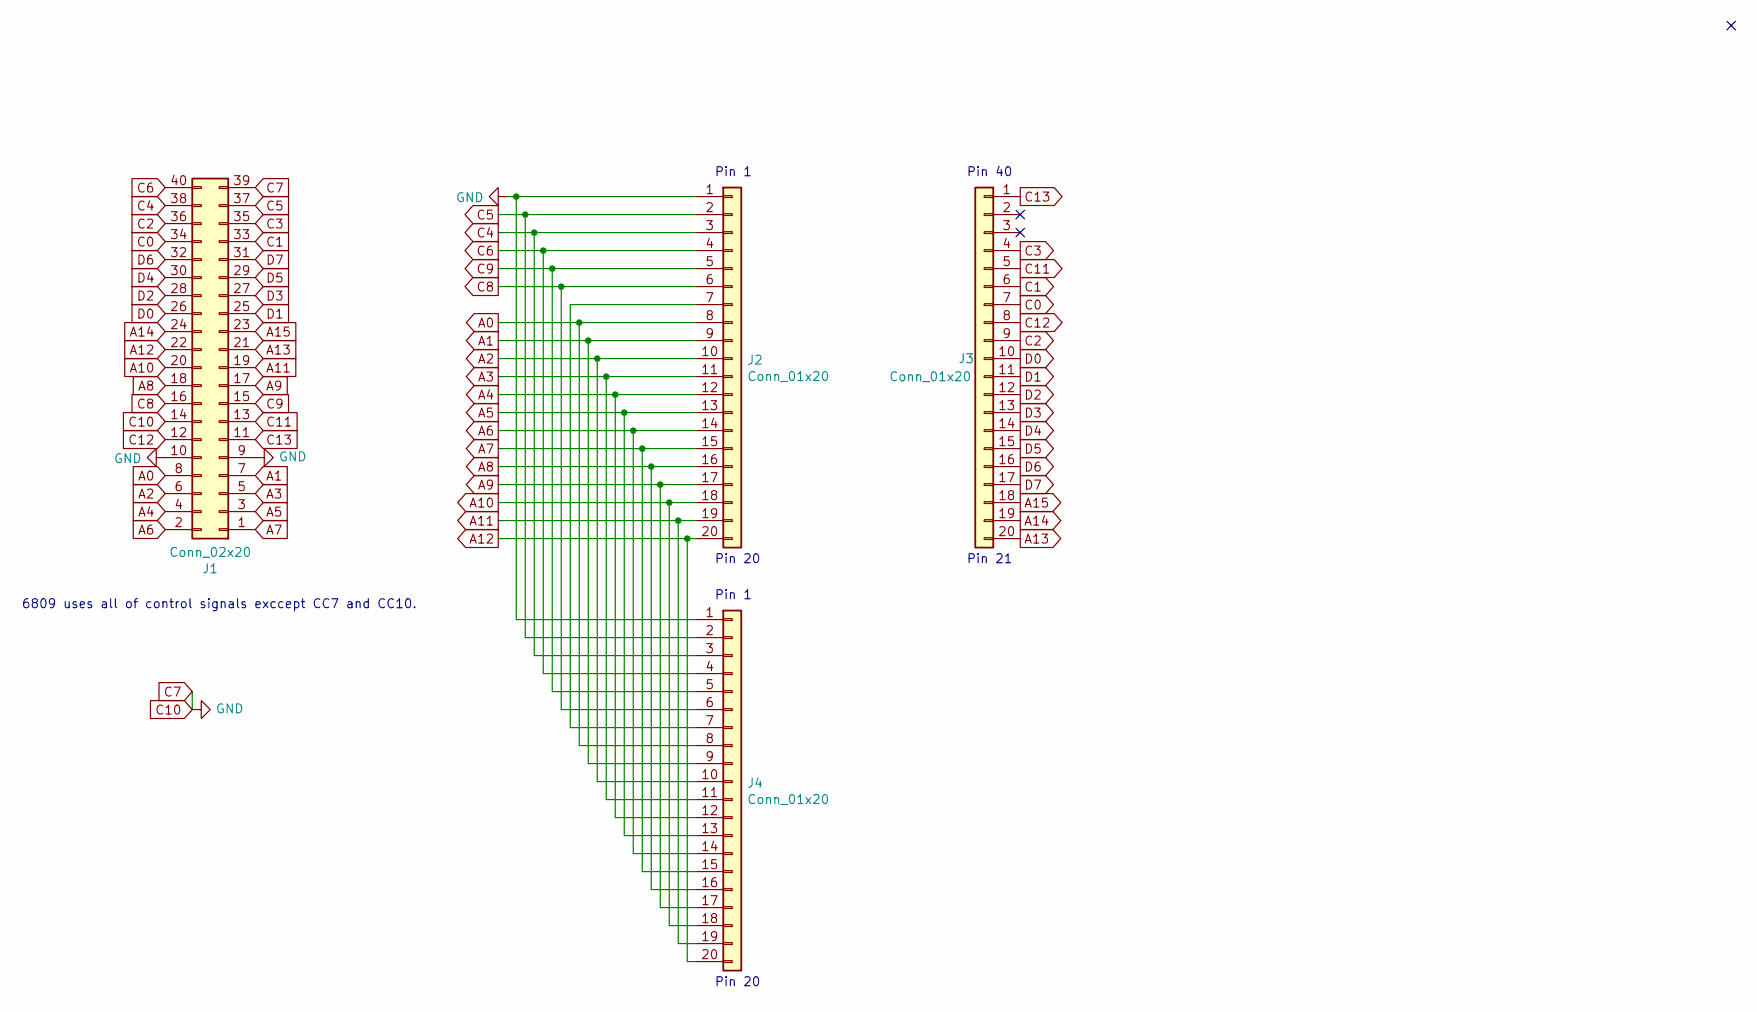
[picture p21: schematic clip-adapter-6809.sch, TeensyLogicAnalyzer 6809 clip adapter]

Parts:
J1: Conn_02x20; PinHeader_2x20_P2.54mm_Vertical
J2, J3, J4: Conn_01x20; PinHeader_1x20_P2.54mm_Vertical

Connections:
A0: J1.8, J2.8, J4.8
A1: J1.7, J2.9, J4.9
A2: J1.6, J2.10, J4.10
A3: J1.5, J2.11, J4.11
A4: J1.4, J2.12, J4.12
A5: J1.3, J2.13, J4.13
A6: J1.2, J2.14, J4.14
A7: J1.1, J2.15, J4.15
A8: J1.18, J2.16, J4.16
A9: J1.17, J2.17, J4.17
A10: J1.20, J2.18, J4.18
A11: J1.19, J2.19, J4.19
A12: J1.22, J2.20, J4.20
A13: J1.21, J3.20
A14: J1.24, J3.19
A15: J1.23, J3.18
C0: J1.34, J3.7
C1: J1.33, J3.6
C2: J1.36, J3.9
C3: J1.35, J3.4
C4: J1.38, J2.3, J4.3
C5: J1.37, J2.2, J4.2
C6: J1.40, J2.4, J4.4
C8: J1.16, J2.6, J4.6
C9: J1.15, J2.5, J4.5
C10: J1.9, J1.10, J1.14, J1.39, J2.1, J4.1
C11: J1.13, J3.5
C12: J1.12, J3.8
C13: J1.11, J3.1
D0: J1.26, J3.10
D1: J1.25, J3.11
D2: J1.28, J3.12
D3: J1.27, J3.13
D4: J1.30, J3.14
D5: J1.29, J3.15
D6: J1.32, J3.16
D7: J1.31, J3.17
unnamed: J2.7, J4.7

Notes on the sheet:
Pin 1
Pin 20
Pin 21
Pin 40
6809 uses all of control signals exccept CC7 and CC10.

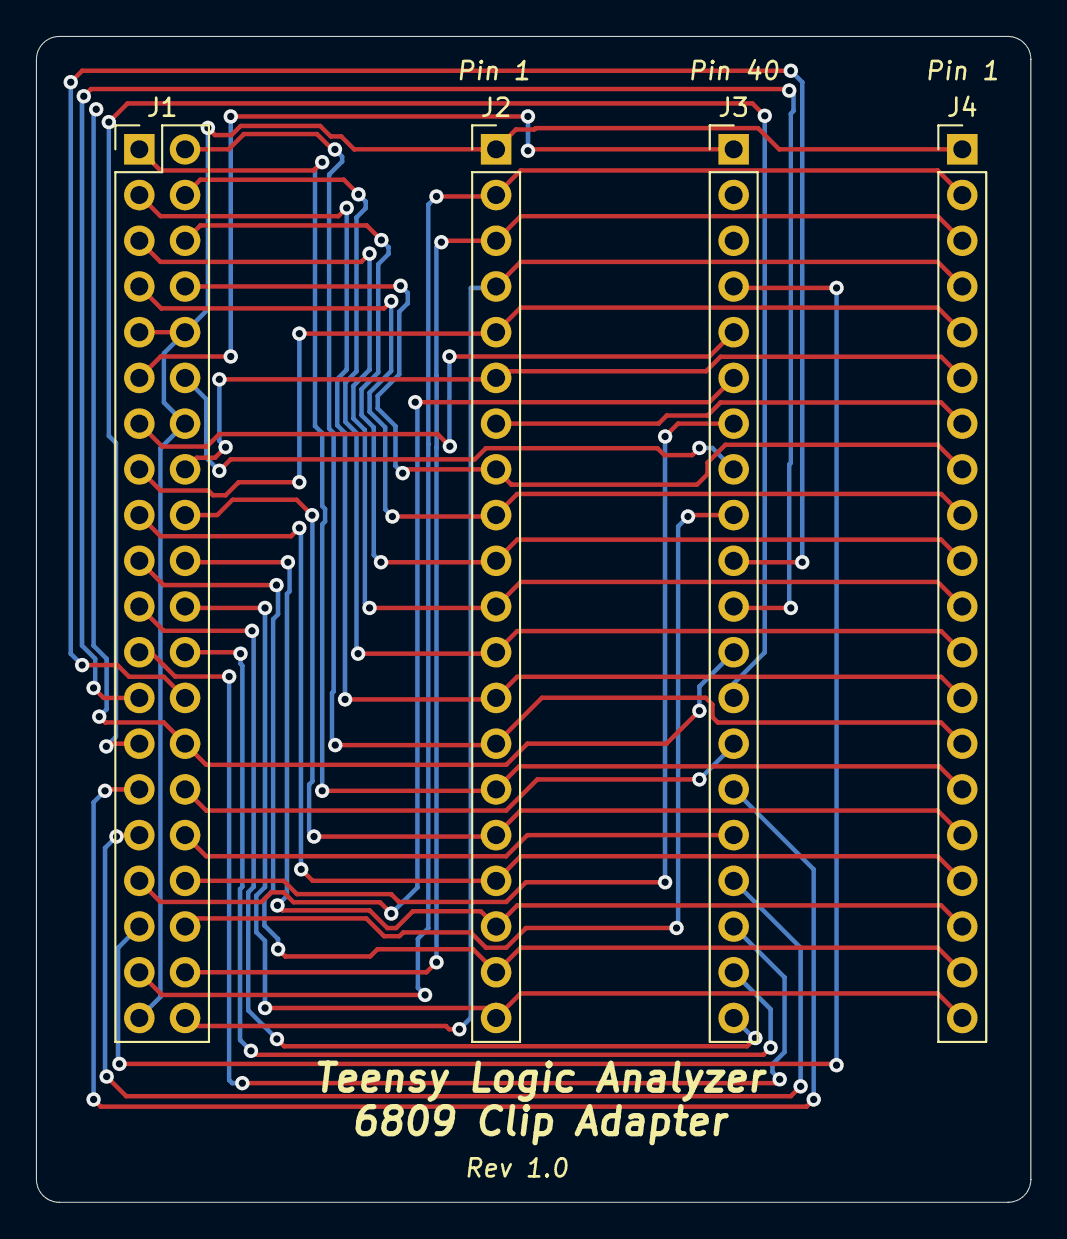
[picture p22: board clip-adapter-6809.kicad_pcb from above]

Board: 2 copper layers, 55.2 x 64.8 mm, 4 parts (0 on the bottom side), 38 nets.

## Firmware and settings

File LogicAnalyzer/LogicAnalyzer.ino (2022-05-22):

/*

  Teensy Logic Analyzer
  Logic Analyzer for 6502, 6800, 6809, or Z80 microprocessors based on a
  Teensy 4.1 microcontroller.

  See https://github.com/thorpej/TeensyLogicAnalyzer

  Based on https://github.com/jefftranter/6502/tree/master/LogicAnalyzer

  Copyright (c) 2022 by Jason R. Thorpe <thorpej@me.com>
  Copyright (c) 2021-2022 by Jeff Tranter <tranter@pobox.com>

  Licensed under the Apache License, Version 2.0 (the "License");
  you may not use this file except in compliance with the License.
  You may obtain a copy of the License at

  http://www.apache.org/licenses/LICENSE-2.0

  Unless required by applicable law or agreed to in writing, software
  distributed under the License is distributed on an "AS IS" BASIS,
  WITHOUT WARRANTIES OR CONDITIONS OF ANY KIND, either express or implied.
  See the License for the specific language governing permissions and
  limitations under the License.

*/

#include <SD.h>

#include "tla.h"
#include "insn_decode.h"

// Maximum buffer size (in samples). Increase if needed; should be
// able to go up to at least 30,000 before running out of memory.
#define BUFFSIZE 5000

const char *versionString = "Teensy Logic Analyzer version 0.4";
const char *verboseVersionStringAdditions = " by Jason R. Thorpe <thorpej@me.com>";
const char *origVersionString = "Based on Logic Analyzer version 0.30 by Jeff Tranter <tranter@pobox.com>";

#define cpu_has_iospace(c)  ((c) == cpu_z80)

// Global variables
uint32_t control[BUFFSIZE];           // Recorded control line data
uint32_t address[BUFFSIZE];           // Recorded address data
uint32_t data[BUFFSIZE];              // Recorded data lines
uint32_t triggerAddress = 0;          // Address to trigger on
uint32_t triggerData = 0;             // Data to trigger on
uint32_t aTriggerBits;                // GPIO bit pattern to trigger address on
uint32_t aTriggerMask;                // bitmask of GPIO address bits
uint32_t cTriggerBits;                // GPIO bit pattern to trigger control on
uint32_t cTriggerMask;                // bitmask of GPIO control bits
uint32_t dTriggerBits;                // GPIO bit pattern to trigger data on
uint32_t dTriggerMask;                // bitmask of GPIO data bits
int samples = 20;                     // Total number of samples to record (up to BUFFSIZE)
int pretrigger = 0;                   // Number of samples to record before trigger (up to samples)
int triggerPoint = 0;                 // Sample in buffer corresponding to trigger point
int samplesTaken = 0;                 // Number of samples taken
trigger_t triggerMode = tr_none;      // Type of trigger
cycle_t triggerCycle = tr_either;     // Trigger on read, write, or either
space_t triggerSpace = tr_mem;        // default to memory space
bool triggerLevel = false;            // Trigger level (false=low, true=high);
volatile bool triggerPressed = false; // Set by hardware trigger button

extern "C" {
  cpu_t cpu = cpu_none;                 // Current CPU type
}

extern "C" {
  __attribute__((__format__(__printf__, 1, 2)))
  int
  tla_printf(const char *fmt, ...)
  {
    static char tla_printf_buf[256];
    va_list ap;
    int rv;

    va_start(ap, fmt);
    rv = vsnprintf(tla_printf_buf, sizeof(tla_printf_buf), fmt, ap);
    va_end(ap);

    Serial.print(tla_printf_buf);

    return rv;
  }
}

void
show_version(bool verbose)
{
  if (verbose) {
    tla_printf("%s%s\n", versionString, verboseVersionStringAdditions);
    tla_printf("%s\n", origVersionString);
  } else {
    tla_printf("%s\n", versionString);
  }
}

//
// MASTER TABLE OF Teensy 4.1 DIGITAL I/O PINS
// In general, these inputs are grouped so e.g. CPU data and address lines can all be read
// from a single 32-bit GPIO port register.
//
//  0 (1.3)  - CA0
//  1 (1.2)  - CA1
//  2 (4.4)  - CC0
//  3 (4.5)  - CC1
//  4 (4.6)  - CC2
//  5 (4.8)  - CC3
//  6 (2.10) - CD0
//  7 (2.17) - CD1
//  8 (2.16) - CD2
//  9 (2.11) - CD3
// 10 (2.0)  - CD4
// 11 (2.2)  - CD5
// 12 (2.1)  - CD6
// 13 -- on-board LED
// 14 (1.18) - CA2
// 15 (1.19) - CA3
// 16 (1.23) - CA4
// 17 (1.22) - CA5
// 18 (1.17) - CA6
// 19 (1.16) - CA7
// 20 (1.26) - CA8
// 21 (1.27) - CA9
// 22 (1.24) - CA10
// 23 (1.25) - CA11
// 24 (1.12) - CA12
// 25 (1.13) - CA13
// 26 (1.30) - CA14
// 27 (1.31) - CA15
// 28 (3.18) -- data bus enable
// 29 (4.31) - CC4
// 30 (3.23) - n/c
// 31 (3.22) -- trigger button
// 32 (2.12) - CD7
// 33 (4.7)  - CC5
// 34 (2.29) - CC7
// 35 (2.28) - CC8
// 36 (2.18) - CC9
// 37 (2.19) - CC10
// 38 (1.28) - CC6
// 39 (1.29) - CC11
// 40 (1.20) - CC12
// 41 (1.21) - CC13
//
// Note that we snoop a total of 38 signals:
// - 16 address signals
// - 8 data signals
// - 14 control signals
//
// This is exactly enough in order to fully probe any 40-pin 8-bit CPU
// (2 pins will always be taken up by Vcc and GND).

#define ENABLE_PIN        28
#define BUTTON_PIN        31

#define CAxx_PSR          CORE_PIN0_PINREG   // All CAxx lines are in the same GPIO port
#define CA0_PIN_BITMASK   CORE_PIN0_BITMASK
#define CA1_PIN_BITMASK   CORE_PIN1_BITMASK
#define CA2_PIN_BITMASK   CORE_PIN14_BITMASK
#define CA3_PIN_BITMASK   CORE_PIN15_BITMASK
#define CA4_PIN_BITMASK   CORE_PIN16_BITMASK
#define CA5_PIN_BITMASK   CORE_PIN17_BITMASK
#define CA6_PIN_BITMASK   CORE_PIN18_BITMASK
#define CA7_PIN_BITMASK   CORE_PIN19_BITMASK
#define CA8_PIN_BITMASK   CORE_PIN20_BITMASK
#define CA9_PIN_BITMASK   CORE_PIN21_BITMASK
#define CA10_PIN_BITMASK  CORE_PIN22_BITMASK
#define CA11_PIN_BITMASK  CORE_PIN23_BITMASK
#define CA12_PIN_BITMASK  CORE_PIN24_BITMASK
#define CA13_PIN_BITMASK  CORE_PIN25_BITMASK
#define CA14_PIN_BITMASK  CORE_PIN26_BITMASK
#define CA15_PIN_BITMASK  CORE_PIN27_BITMASK

#define CDxx_PSR          CORE_PIN6_PINREG    // All CDxx lines are in the same GPIO port  
#define CD0_PIN_BITMASK   CORE_PIN6_BITMASK
#define CD1_PIN_BITMASK   CORE_PIN7_BITMASK
#define CD2_PIN_BITMASK   CORE_PIN8_BITMASK
#define CD3_PIN_BITMASK   CORE_PIN9_BITMASK
#define CD4_PIN_BITMASK   CORE_PIN10_BITMASK
#define CD5_PIN_BITMASK   CORE_PIN11_BITMASK
#define CD6_PIN_BITMASK   CORE_PIN12_BITMASK
#define CD7_PIN_BITMASK   CORE_PIN32_BITMASK

// Control signals are grouped into physical inputs (CCxx_PIN_BITMASK),
// and their logical equivalents (CCxx_BITMASK).  The logical equivalants,
// once normalized re then grouped into their per-CPU meanings (CC_xxx_yyy).

#define CCxx_PSR          CORE_PIN2_PINREG
#define CC0_PIN_BITMASK   CORE_PIN2_BITMASK
#define CC1_PIN_BITMASK   CORE_PIN3_BITMASK
#define CC2_PIN_BITMASK   CORE_PIN4_BITMASK
#define CC3_PIN_BITMASK   CORE_PIN5_BITMASK
#define CC4_PIN_BITMASK   CORE_PIN29_BITMASK
#define CC5_PIN_BITMASK   CORE_PIN33_BITMASK
#define CC6_PIN_BITMASK   CORE_PIN38_BITMASK  // in CAxx_PSR
#define CC7_PIN_BITMASK   CORE_PIN34_BITMASK  // in CDxx_PSR
#define CC8_PIN_BITMASK   CORE_PIN35_BITMASK  // in CDxx_PSR
#define CC9_PIN_BITMASK   CORE_PIN36_BITMASK  // in CDxx_PSR
#define CC10_PIN_BITMASK  CORE_PIN37_BITMASK  // in CDxx_PSR
#define CC11_PIN_BITMASK  CORE_PIN39_BITMASK  // in CAxx_PSR
#define CC12_PIN_BITMASK  CORE_PIN40_BITMASK  // in CAxx_PSR
#define CC13_PIN_BITMASK  CORE_PIN41_BITMASK  // in CAxx_PSR

// The control signals in CDxx_PSR need to be read at the same time as the
// other control signals, which means we need to read the CDxx_PSR twice
// and properly mix the bits from the each read into the final result.
#define CDxx_PSR_CC_MASK  (CC7_PIN_BITMASK | CC8_PIN_BITMASK | CC9_PIN_BITMASK | CC10_PIN_BITMASK)
#define CDxx_PSR_CD_MASK  (~CDxx_PSR_CC_MASK)

// We need to poll certain CC pins, so define constants for
// them here.
#define CC0_PIN           2
#define CC1_PIN           3
#define CC2_PIN           4
#define CC3_PIN           5
#define CC4_PIN           29
#define CC5_PIN           33
#define CC6_PIN           38
#define CC7_PIN           34
#define CC8_PIN           35
#define CC9_PIN           36
#define CC10_PIN          37
#define CC11_PIN          39
#define CC12_PIN          40
#define CC13_PIN          41

#define CC0_BITMASK       (1U <<  0)
#define CC1_BITMASK       (1U <<  1)
#define CC2_BITMASK       (1U <<  2)
#define CC3_BITMASK       (1U <<  3)
#define CC4_BITMASK       (1U <<  4)
#define CC5_BITMASK       (1U <<  5)
#define CC6_BITMASK       (1U <<  6)
#define CC7_BITMASK       (1U <<  7)
#define CC8_BITMASK       (1U <<  8)
#define CC9_BITMASK       (1U <<  9)
#define CC10_BITMASK      (1U << 10)
#define CC11_BITMASK      (1U << 11)
#define CC12_BITMASK      (1U << 12)
#define CC13_BITMASK      (1U << 13)

#define CC_6502_PHI2      CC0_BITMASK
#define CC_6502_SYNC      CC1_BITMASK
#define CC_6502_RW        CC2_BITMASK
#define CC_6502_RESET     CC3_BITMASK
#define CC_6502_IRQ       CC4_BITMASK
#define CC_6502_NMI       CC5_BITMASK
#define CC_6502_RDY       CC6_BITMASK
#define CC_6502_SO        CC7_BITMASK
#define CC_6502_PHI1      CC11_BITMASK

#define CC_6502_PHI1_PIN  CC11_PIN
#define CC_6502_PHI2_PIN  CC0_PIN

#define CC_6800_PHI2      CC0_BITMASK         // same as 6502
#define CC_6800_VMA       CC1_BITMASK
#define CC_6800_RW        CC2_BITMASK         // same as 6502
#define CC_6800_RESET     CC3_BITMASK         // same as 6502
#define CC_6800_IRQ       CC4_BITMASK         // same as 6502
#define CC_6800_NMI       CC5_BITMASK         // same as 6502
#define CC_6800_HALT      CC6_BITMASK
#define CC_6800_DBE       CC7_BITMASK
#define CC_6800_BA        CC8_BITMASK
#define CC_6800_TSC       CC10_BITMASK
#define CC_6800_PHI1      CC11_BITMASK

#define CC_6800_PHI1_PIN  CC11_PIN
#define CC_6800_PHI2_PIN  CC0_PIN

#define CC_6809_E         CC0_BITMASK
#define CC_6809_Q         CC1_BITMASK
#define CC_6809_RW        CC2_BITMASK         // same as 6502
#define CC_6809_RESET     CC3_BITMASK         // same as 6502
#define CC_6809_IRQ       CC4_BITMASK         // same as 6502
#define CC_6809_NMI       CC5_BITMASK         // same as 6502
#define CC_6809_FIRQ      CC6_BITMASK
#define CC_6809E_LIC      CC7_BITMASK
#define CC_6809_BA        CC8_BITMASK
#define CC_6809_BS        CC9_BITMASK
#define CC_6809E_TSC      CC10_BITMASK
#define CC_6809_MRDY      CC11_BITMASK        // NOT 6809E
#define CC_6809E_AVMA     CC11_BITMASK
#define CC_6809_DMA_BREQ  CC12_BITMASK        // NOT 6809E
#define CC_6809E_BUSY     CC12_BITMASK
#define CC_6809_HALT      CC13_BITMASK

#define CC_6809_E_PIN     CC0_PIN
#define CC_6809_Q_PIN     CC1_PIN

#define CC_Z80_CLK        CC0_BITMASK
#define CC_Z80_M1         CC1_BITMASK
#define CC_Z80_MREQ       CC2_BITMASK
#define CC_Z80_IORQ       CC3_BITMASK
#define CC_Z80_RD         CC4_BITMASK
#define CC_Z80_WR         CC5_BITMASK
#define CC_Z80_RESET      CC6_BITMASK
#define CC_Z80_INT        CC7_BITMASK
#define CC_Z80_NMI        CC8_BITMASK
#define CC_Z80_BUSACK     CC9_BITMASK
#define CC_Z80_BUSRQ      CC10_BITMASK
#define CC_Z80_WAIT       CC11_BITMASK
#define CC_Z80_HALT       CC12_BITMASK
#define CC_Z80_RFSH       CC13_BITMASK

#define CC_Z80_CLK_PIN    CC0_PIN

//
// FAKE SAMPLE DATA FOR TEST AND DEBUGGING PURPOSES.  You can only enable
// one of these at a time.
//
// #define DEBUG_6502
// #define DEBUG_6809E
// #define DEBUG_Z80
//
#include "test_samples.h"

// Macros to await signal transitions.
#define WAIT_PHI2_LOW while (digitalReadFast(CC_6502_PHI2_PIN) == HIGH) ;
#define WAIT_PHI2_HIGH while (digitalReadFast(CC_6502_PHI2_PIN) == LOW) ;
#define WAIT_Q_LOW while (digitalReadFast(CC_6809_Q) == HIGH) ;
#define WAIT_Q_HIGH while (digitalReadFast(CC_6809_Q) == LOW) ;
#define WAIT_E_LOW while (digitalReadFast(CC_6809_E) == HIGH) ;
#define WAIT_E_HIGH while (digitalReadFast(CC_6809_E) == LOW) ;
#define WAIT_CLK_LOW while (digitalReadFast(CC_Z80_CLK_PIN) == HIGH) ;
#define WAIT_CLK_HIGH while (digitalReadFast(CC_Z80_CLK_PIN) == LOW) ;

uint32_t
scramble_CAxx(uint32_t ca)
{
  return ((ca & (1U <<  0)) ?  CA0_PIN_BITMASK : 0) |
         ((ca & (1U <<  1)) ?  CA1_PIN_BITMASK : 0) |
         ((ca & (1U <<  2)) ?  CA2_PIN_BITMASK : 0) |
         ((ca & (1U <<  3)) ?  CA3_PIN_BITMASK : 0) |
         ((ca & (1U <<  4)) ?  CA4_PIN_BITMASK : 0) |
         ((ca & (1U <<  5)) ?  CA5_PIN_BITMASK : 0) |
         ((ca & (1U <<  6)) ?  CA6_PIN_BITMASK : 0) |
         ((ca & (1U <<  7)) ?  CA7_PIN_BITMASK : 0) |
         ((ca & (1U <<  8)) ?  CA8_PIN_BITMASK : 0) |
         ((ca & (1U <<  9)) ?  CA9_PIN_BITMASK : 0) |
         ((ca & (1U << 10)) ? CA10_PIN_BITMASK : 0) |
         ((ca & (1U << 11)) ? CA11_PIN_BITMASK : 0) |
         ((ca & (1U << 12)) ? CA12_PIN_BITMASK : 0) |
         ((ca & (1U << 13)) ? CA13_PIN_BITMASK : 0) |
         ((ca & (1U << 14)) ? CA14_PIN_BITMASK : 0) |
         ((ca & (1U << 15)) ? CA15_PIN_BITMASK : 0);
}

uint32_t
unscramble_CAxx(uint32_t reg)
{
  return ((reg &  CA0_PIN_BITMASK) ? (1U <<  0) : 0) |
         ((reg &  CA1_PIN_BITMASK) ? (1U <<  1) : 0) |
         ((reg &  CA2_PIN_BITMASK) ? (1U <<  2) : 0) |
         ((reg &  CA3_PIN_BITMASK) ? (1U <<  3) : 0) |
         ((reg &  CA4_PIN_BITMASK) ? (1U <<  4) : 0) |
         ((reg &  CA5_PIN_BITMASK) ? (1U <<  5) : 0) |
         ((reg &  CA6_PIN_BITMASK) ? (1U <<  6) : 0) |
         ((reg &  CA7_PIN_BITMASK) ? (1U <<  7) : 0) |
         ((reg &  CA8_PIN_BITMASK) ? (1U <<  8) : 0) |
         ((reg &  CA9_PIN_BITMASK) ? (1U <<  9) : 0) |
         ((reg & CA10_PIN_BITMASK) ? (1U << 10) : 0) |
         ((reg & CA11_PIN_BITMASK) ? (1U << 11) : 0) |
         ((reg & CA12_PIN_BITMASK) ? (1U << 12) : 0) |
         ((reg & CA13_PIN_BITMASK) ? (1U << 13) : 0) |
         ((reg & CA14_PIN_BITMASK) ? (1U << 14) : 0) |
         ((reg & CA15_PIN_BITMASK) ? (1U << 15) : 0);
}

uint32_t
scramble_CDxx(uint32_t cd)
{
    return ((cd & (1U << 0)) ? CD0_PIN_BITMASK : 0) |
           ((cd & (1U << 1)) ? CD1_PIN_BITMASK : 0) |
           ((cd & (1U << 2)) ? CD2_PIN_BITMASK : 0) |
           ((cd & (1U << 3)) ? CD3_PIN_BITMASK : 0) |
           ((cd & (1U << 4)) ? CD4_PIN_BITMASK : 0) |
           ((cd & (1U << 5)) ? CD5_PIN_BITMASK : 0) |
           ((cd & (1U << 6)) ? CD6_PIN_BITMASK : 0) |
           ((cd & (1U << 7)) ? CD7_PIN_BITMASK : 0);
}

uint32_t
unscramble_CDxx(uint32_t reg)
{
  return ((reg & CD0_PIN_BITMASK) ? (1U << 0) : 0) |
         ((reg & CD1_PIN_BITMASK) ? (1U << 1) : 0) |
         ((reg & CD2_PIN_BITMASK) ? (1U << 2) : 0) |
         ((reg & CD3_PIN_BITMASK) ? (1U << 3) : 0) |
         ((reg & CD4_PIN_BITMASK) ? (1U << 4) : 0) |
         ((reg & CD5_PIN_BITMASK) ? (1U << 5) : 0) |
         ((reg & CD6_PIN_BITMASK) ? (1U << 6) : 0) |
         ((reg & CD7_PIN_BITMASK) ? (1U << 7) : 0);
}

uint32_t
scramble_CCxx(uint32_t cc, uint32_t *aregp, uint32_t *dregp)
{
  if (cc & CC6_BITMASK) {
    *aregp |= CC6_PIN_BITMASK;
  }
  if (cc & CC11_BITMASK) {
    *aregp |= CC11_PIN_BITMASK;
  }
  if (cc & CC12_BITMASK) {
    *aregp |= CC12_PIN_BITMASK;
  }
  if (cc & CC13_BITMASK) {
    *aregp |= CC13_PIN_BITMASK;
  }

  if (cc & CC7_BITMASK) {
    *dregp |= CC7_PIN_BITMASK;
  }
  if (cc & CC8_BITMASK) {
    *dregp |= CC8_PIN_BITMASK;
  }
  if (cc & CC9_BITMASK) {
    *dregp |= CC9_PIN_BITMASK;
  }
  if (cc & CC10_BITMASK) {
    *dregp |= CC10_PIN_BITMASK;
  }

  return ((cc & CC0_BITMASK) ? CC0_PIN_BITMASK : 0) |
         ((cc & CC1_BITMASK) ? CC1_PIN_BITMASK : 0) |
         ((cc & CC2_BITMASK) ? CC2_PIN_BITMASK : 0) |
         ((cc & CC3_BITMASK) ? CC3_PIN_BITMASK : 0) |
         ((cc & CC4_BITMASK) ? CC4_PIN_BITMASK : 0) |
         ((cc & CC5_BITMASK) ? CC5_PIN_BITMASK : 0);
}

uint32_t
unscramble_CCxx(uint32_t creg, uint32_t areg, uint32_t dreg)
{
  return ((creg &  CC0_PIN_BITMASK) ?  CC0_BITMASK : 0) |
         ((creg &  CC1_PIN_BITMASK) ?  CC1_BITMASK : 0) |
         ((creg &  CC2_PIN_BITMASK) ?  CC2_BITMASK : 0) |
         ((creg &  CC3_PIN_BITMASK) ?  CC3_BITMASK : 0) |
         ((creg &  CC4_PIN_BITMASK) ?  CC4_BITMASK : 0) |
         ((creg &  CC5_PIN_BITMASK) ?  CC5_BITMASK : 0) |
         // CC6 is in the areg
         ((areg &  CC6_PIN_BITMASK) ?  CC6_BITMASK : 0) |
         // CC7-10 are in the dreg
         ((dreg &  CC7_PIN_BITMASK) ?  CC7_BITMASK : 0) |
         ((dreg &  CC8_PIN_BITMASK) ?  CC8_BITMASK : 0) |
         ((dreg &  CC9_PIN_BITMASK) ?  CC9_BITMASK : 0) |
         ((dreg & CC10_PIN_BITMASK) ? CC10_BITMASK : 0) |
         // CC11-13 are in the areg
         ((areg & CC11_PIN_BITMASK) ? CC11_BITMASK : 0) |
         ((areg & CC12_PIN_BITMASK) ? CC12_BITMASK : 0) |
         ((areg & CC13_PIN_BITMASK) ? CC13_BITMASK : 0);
}

// Rearrange sampled bits of data in buffer back into address, data,
// and control lines.
void
unscramble(void)
{
  for (int i = 0; i < samples; i++) {
    // Unscramble control signals first; some of them have bits in
    // the data and address line GPIO ports.
    control[i] = unscramble_CCxx(control[i], address[i], data[i]);
    address[i] = unscramble_CAxx(address[i]);
    data[i]    = unscramble_CDxx(data[i]);
   }
}

void
setBusEnabled(bool e)
{
  digitalWriteFast(ENABLE_PIN, e ? LOW : HIGH);
}

// Startup function
void
setup(void)
{
  // Configure all of the pins.  We use all of the digital I/O
  // pins vailable on the Teensy 4.1 board.
  for (int i = 0; i <= 41; i++) {
    switch (i) {
      case CORE_LED0_PIN:
        // LED pin is push-pull ouput.  This is used to indicate
        // that we're waiting to trigger.
        pinMode(CORE_LED0_PIN, OUTPUT);
        break;

      case ENABLE_PIN:
        // ENABLE pin is an open-drain output (there is a pull-up
        // resistor connected to the /CE inputs of the 74LVC245s).
        pinMode(ENABLE_PIN, OUTPUT_OPENDRAIN);
        setBusEnabled(false);
        break;

      case BUTTON_PIN:
        // The button goes to ground; we need to figure as an
        // input-pullup.  Interrupt is triggered on the falling
        // edge.
        pinMode(BUTTON_PIN, INPUT_PULLUP);
        break;

      default:
        // Every other pin is configured as an input.  *No* pull-up;
        // the 74LVC245 has push-pull outputs.
        pinMode(i, INPUT);
        break;
    }
  }

  // Manual trigger button - low on this pin forces a trigger.
  attachInterrupt(digitalPinToInterrupt(BUTTON_PIN), triggerButton, FALLING);

  Serial.begin(115200);
  while (!Serial) {
    ; // wait for serial port to connect. Needed for native USB.
  }

  Serial.setTimeout(60000);
  show_version(false);
  tla_printf("Type \"h\" or \"?\" for help.\n");
}

// Interrupt handler for trigger button.
void
triggerButton(void)
{
  triggerPressed = true;
}

const char *
cpu_name(void)
{
  switch (cpu) {
    case cpu_6502:    return "6502";
    case cpu_65c02:   return "65C02";
    case cpu_6800:    return "6800";
    case cpu_6809:    return "6809";
    case cpu_6809e:   return "6809E";
    case cpu_z80:     return "Z80";
    default:          return "not set";
  }
}

void
show_cpu(void)
{
  tla_printf("CPU: %s\n", cpu_name());
}

void
set_cpu(cpu_t ncpu)
{
  if (triggerSpace == tr_io && !cpu_has_iospace(ncpu)) {
    triggerSpace = tr_mem;
    triggerMode = tr_none;
  }
  cpu = ncpu;
}

const char *
trigger_signal_name(trigger_t t)
{
  switch (t) {
    case tr_reset:    return "/RESET";
    case tr_irq:      return cpu == cpu_z80 ? "/INT" : "/IRQ";
    case tr_firq:     return "/FIRQ";
    case tr_nmi:      return "/NMI";
    default:          return "<unknown>";
  }
}

const char *
trigger_cycle_name(cycle_t c)
{
  switch (c) {
    case tr_read:       return "read";
    case tr_write:      return "write";
    case tr_either:     return "read or write";
    default:            return "<unknown>";
  }
}
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
void
loop(void)
{
  const struct tla_command *cmd, *foundcmd;
  unsigned int ci;

  while (true) {
    Serial.print("% "); // Command prompt
    Serial.flush();

    memset(cmdbuf, 0, sizeof(cmdbuf));
    ci = 0;

    while (true) {
      int c = Serial.read();
      if ((c == '\r') || (c == '\n')) {
        // End of command line.
        cmdbuf[ci] = '\0';
        break;
      }

      if ((c == '\b') || (c == 0x7f)) { // Handle backspace or delete
        if (ci > 0) {
          ci--;                  // Remove last character
          Serial.print("\b \b"); // Backspace over last character entered.
          continue;
        }
      }
      if (c != -1 && ci <= CMDBUF_LEN - 1) {
        Serial.write((char)c);  // Echo character
        cmdbuf[ci++] = (char)c; // Append to command string
      }
    }

    Serial.println("");
    memcpy(saved_cmdbuf, cmdbuf, sizeof(saved_cmdbuf));

    if (!tokenizeCommand()) {
      invalidCommand();
      continue;
    }

    if (argc == 0) {
      continue;
    }

    foundcmd = NULL;
    if ((cmd = lookupCommand(argv[0], NULL)) != NULL) {
      if (foundcmd == NULL) {
        foundcmd = cmd;
        cmd = lookupCommand(argv[0], foundcmd + 1);
        if (cmd != NULL) {
          tla_printf("Ambiguous command: '%s'\n", saved_cmdbuf);
          continue;
        }
      }
    }
    if (foundcmd == NULL) {
      invalidCommand();
    }
    foundcmd->cmdfunc();
  }
}

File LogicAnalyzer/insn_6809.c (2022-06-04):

/*

  Teensy Logic Analyzer
  Logic Analyzer for 6502, 6800, 6809, or Z80 microprocessors based on a
  Teensy 4.1 microcontroller.

  See https://github.com/thorpej/TeensyLogicAnalyzer

  Copyright (c) 2022 by Jason R. Thorpe <thorpej@me.com>

  Licensed under the Apache License, Version 2.0 (the "License");
  you may not use this file except in compliance with the License.
  You may obtain a copy of the License at

  http://www.apache.org/licenses/LICENSE-2.0

  Unless required by applicable law or agreed to in writing, software
  distributed under the License is distributed on an "AS IS" BASIS,
  WITHOUT WARRANTIES OR CONDITIONS OF ANY KIND, either express or implied.
  See the License for the specific language governing permissions and
  limitations under the License.

*/

#include "tla.h"
#include "insn_decode.h"

//
// 6809 instruction decoding
//
#define POSTBYTES(am, n) [(am) - am6809_first] = (n)
const uint8_t
static insn_postbytes_6809[] = {
  POSTBYTES(am6809_inherent,        0),
  POSTBYTES(am6809_direct,          1),
  POSTBYTES(am6809_extended,        2),
  POSTBYTES(am6809_rel8,            1),
  POSTBYTES(am6809_rel16,           2),
  POSTBYTES(am6809_imm8,            1),
  POSTBYTES(am6809_imm16,           2),
  POSTBYTES(am6809_zero_off,        1),
  POSTBYTES(am6809_zero_off_ind,    1),
  POSTBYTES(am6809_const_off5,      1),
  POSTBYTES(am6809_const_off8,      2),
  POSTBYTES(am6809_const_off8_ind,  2),
  POSTBYTES(am6809_const_off16,     3),
  POSTBYTES(am6809_const_off16_ind, 3),
  POSTBYTES(am6809_acc_off,         1),
  POSTBYTES(am6809_acc_off_ind,     1),
  POSTBYTES(am6809_post_inc1,       1),
  POSTBYTES(am6809_post_inc2,       1),
  POSTBYTES(am6809_post_inc2_ind,   1),
  POSTBYTES(am6809_pre_dec1,        1),
  POSTBYTES(am6809_pre_dec2,        1),
  POSTBYTES(am6809_pre_dec2_ind,    1),
  POSTBYTES(am6809_pcrel8,          2),
  POSTBYTES(am6809_pcrel8_ind,      2),
  POSTBYTES(am6809_pcrel16,         3),
  POSTBYTES(am6809_pcrel16_ind,     3),
  POSTBYTES(am6809_extended_ind,    3),
  POSTBYTES(am6809_exg_tfr,         1),
  POSTBYTES(am6809_psh_pul,         1),
};
#undef POSTBYTES

static const char *opcodes_6809[256] = {
  "NEG",  "?",    "?",    "COM",  "LSR",  "?",    "ROR",  "ASR",
  "ASL",  "ROL",  "DEC",  "?",    "INC",  "TST",  "JMP",  "CLR",
  "(pg2)","(pg3)","NOP",  "SYNC", "?",    "?",    "LBRA", "LBSR",
  "?",    "DAA",  "ORCC", "?",    "ANDCC","SEX",  "EXG",  "TFR",
  "BRA",  "BRN",  "BHI",  "BLS",  "BCC",  "BCS",  "BNE",  "BEQ",
  "BVC",  "BVS",  "BPL",  "BMI",  "BGE",  "BLT",  "BGT",  "BLE",
  "LEAX", "LEAY", "LEAS", "LEAU", "PSHS", "PULS", "PSHU", "PULU",
  "?",    "RTS",  "ABX",  "RTI",  "CWAI", "MUL",  "?",    "SWI",
  "NEGA", "?",    "?",    "COMA", "LSRA", "?",    "RORA", "ASRA",
  "ASLA", "ROLA", "DECA", "?",    "INCA", "TSTA", "?",    "CLRA",
  "NEGB", "?",    "?",    "COMB", "LSRB", "?",    "RORB", "ASRB",
  "ASLB", "ROLB", "DECB", "?",    "INCB", "TSTB", "?",    "CLRB",
  "NEG",  "?",    "?",    "COM",  "LSR",  "?",    "ROR",  "ASR",
  "ASL",  "ROL",  "DEC",  "?",    "INC",  "TST",  "JMP",  "CLR",
  "NEG",  "?",    "?",    "COM",  "LSR",  "?",    "ROR",  "ASR",
  "ASL",  "ROL",  "DEC",  "?",    "INC",  "TST",  "JMP",  "CLR",
  "SUBA", "CMPA", "SBCA", "SUBD", "ANDA", "BITA", "LDA",  "?",
  "EORA", "ADCA", "ORA",  "ADDA", "CMPX", "BSR",  "LDX",  "?",
  "SUBA", "CMPA", "SBCA", "SUBD", "ANDA", "BITA", "LDA",  "STA",
  "EORA", "ADCA", "ORA",  "ADDA", "CMPX", "JSR",  "LDX",  "STX",
  "SUBA", "CMPA", "SBCA", "SUBD", "ANDA", "BITA", "LDA",  "STA",
  "EORA", "ADCA", "ORA",  "ADDA", "CMPX", "JSR",  "LDX",  "STX",
  "SUBA", "CMPA", "SBCA", "SUBD", "ANDA", "BITA", "LDA",  "STA",
  "EORA", "ADCA", "ORA",  "ADDA", "CMPX", "JSR",  "LDX",  "STX",
  "SUBB", "CMPB", "SBCB", "ADDD", "ANDB", "BITB", "LDB",  "?",
  "EORB", "ADCB", "ORB",  "ADDB", "LDD",  "?",    "LDU",  "?",
  "SUBB", "CMPB", "SBCB", "ADDD", "ANDB", "BITB", "LDB",  "STB",
  "EORB", "ADCB", "ORB",  "ADDB", "LDD",  "STD",  "LDU",  "STU",
  "SUBB", "CMPB", "SBCB", "ADDD", "ANDB", "BITB", "LDB",  "STB",
  "EORB", "ADCB", "ORB",  "ADDB", "LDD",  "STD",  "LDU",  "STU",
  "SUBB", "CMPB", "SBCB", "ADDD", "ANDB", "BITB", "LDB",  "STB",
  "EORB", "ADCB", "ORB",  "ADDB", "LDD",  "STD",  "LDU",  "STU"
};

static const char *opcodes_long_cond_branches_6809[] = {
  "?",    "LBRN", "LBHI", "LBLS", "LBCC", "LBCS", "LBNE", "LBEQ",
  "LBVC", "LBVS", "LBPL", "LBMI", "LBGE", "LBLT", "LBGT", "LBLE"
};

static addrmode_t
insn_decode_addrmode_indexed_6809(uint8_t pb)
{
  // Refer to "TABLE 2 - INDEXED ADDRESSING MODE" in the 6809 data sheet.
  addrmode_t am;

  // Extended indirect is a slightly special case.
  if ((pb & 0b10011111) == 0b10011111) {
    return am6809_extended_ind;
  }

  // 5-bit constant offset also is a special case.
  if ((pb & 0b10000000) == 0) {
    return am6809_const_off5;
  }

  switch (pb & 0b10001111) {
    case 0b10000100:
      am = am6809_zero_off;
      break;

    case 0b10001000:
      am = am6809_const_off8;
      break;

    case 0b10001001:
      am = am6809_const_off16;
      break;

    case 0b10000110:
    case 0b10000101:
    case 0b10001011:
      am = am6809_acc_off;
      break;

    case 0b10000000:
      am = am6809_post_inc1;
      break;

    case 0b10000001:
      am = am6809_post_inc2;
      break;

    case 0b10000010:
      am = am6809_pre_dec1;
      break;

    case 0b10000011:
      am = am6809_pre_dec2;
      break;

    case 0b10001100:
      am = am6809_pcrel8;
      break;

    case 0b10001101:
      am = am6809_pcrel16;
      break;

    default:
      return am_invalid;
  }

  if (pb & 0b00010000) {
    // Indirect flag.
    if (am == am6809_post_inc1 || am == am6809_pre_dec1) {
      // Indirect not allowed in this case.
      return am_invalid;
    }
    am = (addrmode_t)((int)am + 1);
  }

  return am;
}
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

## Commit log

2022-04-23 Major cleanup of signal inputs: - Keep a master list of pins that are in-use on the Teensy 4.1 board, and reference which GPIO port they're part of. - Define macros for the A0-15 D0-7 and Cx inputs i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
2022-04-23 Remove some unnecessary pin definitions.
2022-04-23 In list(), use symbolic constants for the control signals, and add FIRQ in the 6809 case.
2022-04-23 Define control signals CC10 - CC13. This gives us a total of 38 signals to snoop (16 address, 8 data, 14 control) which is enough for any 40-pin CPU (because 2 of the pins are Vcc and GND).
    Assign the following signals for the 6809E:
    CC10 -- TSC (tri-state control)
    CC11 -- AVMA (advance VMA)
    CC12 -- BUSY
    CC13 -- /HALT (this one is used by the CoCo floppy controller)
    We're not using these signals in software yet, but at least they'll
    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
2022-04-24 Add a TODO to somehow utilize all of the control signals, since we now capture all of them for each of the supported 40-pin CPUs.
2022-04-24 Assign CC_6502_SO, CC_6502_PHI1, and CC_6800_PHI1 for completeness. Define CC_6502_PHI1_PIN and CC_6800_PHI1_PIN in case we ever want to act on those clock signal transitions.
2022-04-24 Define D28 as a data bus enable pin, configured as an open-drain output. The /CE signals of the '245s will be connected to an external pull-up resistor to keep them high-Z until we're ready to actual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
2022-04-24 Because some control signals are in the CDxx_PSR, we need to also read that register when we read the CCxx_PSR and CAxx_PSR. We must then mix the appropriate set of bits together to store as the data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
2022-04-29 This board is input-only, not bi-directional like Tranter's (it's not really compatible with how I've mixed additional control signals into the same GPIO ports as address and data lines).
2022-04-30 Update README.md
    Analyzer board is final; update info about it.
2022-05-01 Rev 1.0 design files for the analyzer main board and clip adapter boards for 6502, 6800, 6809, 6809E, and Z80.
    [analyzer-board.kicad_pcb, analyzer-board.sch, clip-adapter-6502.kicad_pcb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]
2022-05-01 Fix PCB revision -- it's 1.0.
    [analyzer-board.kicad_pcb]
2022-05-01 Add analyzer main board images.
2022-05-01 Add Gerber files.
2022-05-03 Switch to a new state-machine instruction decoder. Just implemented for 6809E so far. 6502 and Z80 coming next. 6800 is left out in the cold (no first-cycle indicator).
2022-05-03 Compute the resolved address for PC-relative operations.
    [LogicAnalyzer.ino]
2022-05-04 Convert the 6502 insn decode to the new style. This mostly works the way Tranter's original does, except with the stateful collection of insn bytes (avoids errors at the ring buffer boundary conditio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
    [LogicAnalyzer.ino]
2022-05-04 Actually wire in the 6502 decoder.
2022-05-05 Default cpu type to "none". Add commands to show current CPU, sample and pre-trigger sample count, and trigger.
2022-05-05 If no samples have been taken, don't show the sample data (and don't overwrite good sample data on the SD card with empty samples data).
2022-05-05 Add a hook for specifying fake samples for debugging. Enabled at compile time only; normally, this will be disabled. Add a bunch of fake samples for 6809E that, while not being cycle-accurate in any 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
2022-05-06 Add 6502 debug sample data to exercise the instruction decoder.
2022-05-09 Fix a few bugs in the new insn decoder: - read_u16be() had a typo that caused an out-of-bounds memory access. - Fix 6502 / 65c02 relative addressing mode templates. - Fix visual alignment of am6502_r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
    [LogicAnalyzer.ino]
2022-05-09 When print "*" as the cycle type for insn fetch continuations.
2022-05-09 Print the resolved PC-relative address, if computed.
    [LogicAnalyzer.ino]
2022-05-09 Fix decoding the A register in the accumulator-offset indexed mode for 6809, and correct a typo in the test cases for tha mode.
    [LogicAnalyzer.ino]
2022-05-09 Fix some opcode errors in the test cases.
    [LogicAnalyzer.ino]
2022-05-09 - Fix some 65c02 addressing modes. - in writeSD(), be verbose if cpu type isn't set.
    [LogicAnalyzer.ino]
2022-05-10 Add the cycle-by-cycle flow examples from the 6809E data sheet to the test samples.
2022-05-14 Fix the pcrel operand type in z80_operand_types[].
    [LogicAnalyzer.ino]
2022-05-14 - Fix a bug in cursor advancement in z80_next_operand(). - Add Z80 debug data for the 8-bit load group.
    [LogicAnalyzer.ino]
2022-05-14 Fix a couple of comments.
    [LogicAnalyzer.ino]
2022-05-15 - Add test vectors for the 16-bit LD group. - Fix a bug in z80_hl_to_index() that caused "LD (XXXXh),IX" to be decoded incorrectly.
    [LogicAnalyzer.ino]
2022-05-15 - Add a bunch of additional test vectors for Z80, covering all of the remaining instruction decoder cases. - Fix a think-o in the last commit to z80_hl_to_index(). - In insn_decode_format_z80(), don'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
    [LogicAnalyzer.ino]
2022-05-16 Fix a mistake in 6809E LIC handling: An opcode fetch has started /only/ when we observe LIC transitioning from high to low. So, don't consider an LIC seen on the last sample if LIC is still set on th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
    [LogicAnalyzer.ino]
2022-05-17 Refactor the test sample data into its own header file.
2022-05-17 Condense a bunch of the Serial.print*() calls into an easier-to-use tla_printf().
2022-05-17 Put __format__ attribute on the tla_printf() prototype.
2022-05-18 Make tla_printf() work like normal printf(), and fix up several help messages.
    [LogicAnalyzer.ino]
2022-05-18 Allow prefix matching on commands. No need for short aliases.
    [LogicAnalyzer.ino]
2022-05-18 Fix an instance of "hi" that should be "high".
    [LogicAnalyzer.ino]
2022-05-22 Make sure to configure the button pin as an INPUT_PULLUP.
2022-05-22 Make trigger mode "none" distinct from manual triggering. "manual" is now what "none" used to be (wait for button press), "none" now immediately begins gathering samples without waiting for any sort 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
2022-05-22 Fix a PCB error: The wrong footprint was used for the 6mm push button, causing the button input pin on the Teensy to be connected directly to ground. Fix this problem by using the correct footprint a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
    Bump schematic and PCB rev to 1.1.
    [analyzer-board.kicad_pcb, analyzer-board.sch]
2022-06-04 Correct resolved address calculation on 6809.
    [insn_6809.c]

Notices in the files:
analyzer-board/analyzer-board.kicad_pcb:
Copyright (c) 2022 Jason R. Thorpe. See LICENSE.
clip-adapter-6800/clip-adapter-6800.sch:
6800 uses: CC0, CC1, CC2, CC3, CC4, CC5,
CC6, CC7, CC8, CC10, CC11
